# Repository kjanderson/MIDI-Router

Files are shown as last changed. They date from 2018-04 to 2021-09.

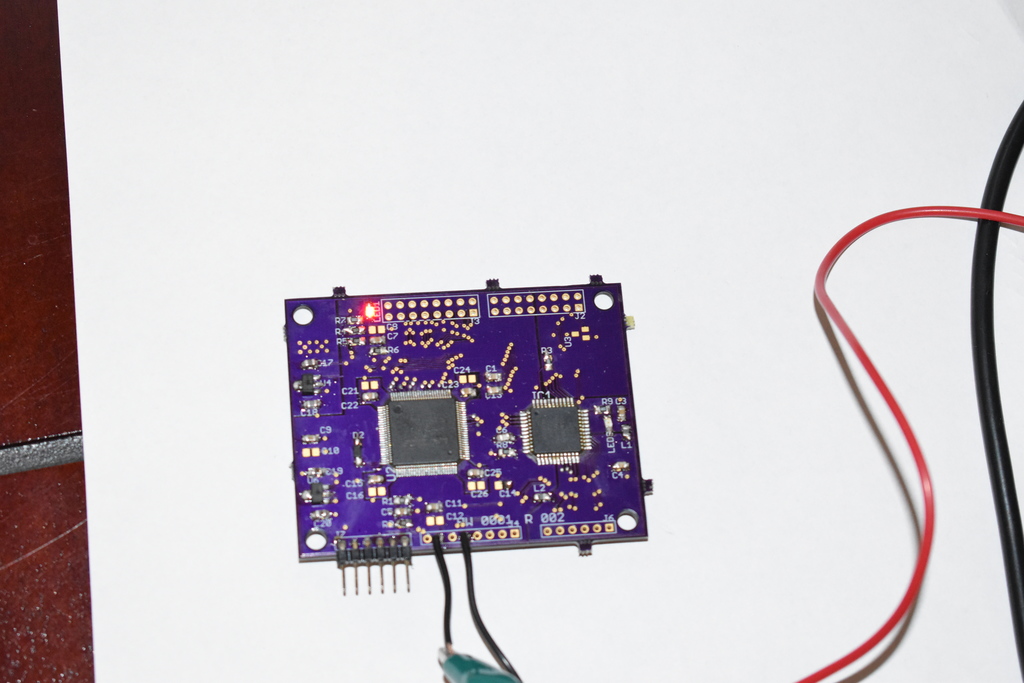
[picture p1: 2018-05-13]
05-implementation/01-pcb/MCU/eagle/mcu-pcb-bringup.jpg

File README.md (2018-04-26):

# MIDI-Router
PIC24/FPGA code to route MIDI data on prototype hardware.

The objective of this project is to build a prototype that is able to route MIDI
signals from source to destination automatically.

The hardware provides 4 MIDI inputs, 4 MIDI thru's, and 4 MIDI outputs.
This software project implements the routing of the inputs to the outputs.

Notes
 - USB is copied from the MLA USB Framework
 - USB-app is copied from the application example in the MLA
 - USB-bsp is copied from the application example in the MLA

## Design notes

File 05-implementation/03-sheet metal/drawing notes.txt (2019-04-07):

Mike@SchorrMetals.com
24 gauge steel, drawing, qty.

panel outline dimensions
    426 mm (16.772 inch) wide
    37.0 mm (1.457 inch) tall
screw hole positions
    1.109 inches vertical
    2.70, 3.2974 mm (0.106, 0.130 inch), 4.5 mm (0.177 inch) diameter
    2.70, 33.697 mm (0.106, 1.327 inch), 4.5 mm (0.177 inch) diameter
    42.00, 3.7974 mm (1.654, 0.150 inch), 4.0 mm (0.157 inch) diameter
    213.00, 3.7974 mm (8.386, 0.150 inch), 4.0 mm (0.157 inch) diameter
    384.00, 3.7974 mm (15.118, 0.150 inch), 4.0 mm (0.157 inch) diameter
    423.30, 3.2974 mm (16.665, 0.130 inch), 4.5 mm (0.177 inch) diameter
    423.30, 33.6974 mm (16.665, 1.327 inch), 4.5 mm (0.177 inch) diameter

120 outlet
holes: 3.5 mm (0.138 inch) diameter
       36 mm (1.417 inch) apart
cutout: 27.3 mm (1.075 inch) tall
        31.4 mm (1.236 inch) wide

USB connector
holes: 3.20 mm (0.126 inch) diameter
       22.0 mm (0.866 inch) apart
cutout: 13.70 mm (0.539 inch) tall
        14.70 mm (0.579 inch) wide

120 outlet
holes: 3.4 mm (0.134 inch)
       40.0 mm (1.575 inch) apart
cutout: 30.3 mm (1.193 inch) wide
        22.3 mm (0.878 inch) tall

spacing of back panel:
    1.0 mm thick bottom
    1.0 mm thick top
    0.75 mm gap between bottom
    0.75 mm gap between top
    0.25 mm gap to bottom lip
    1.5 mm bottom lip
    0.25 mm gap to top lip
    1.5 mm top lip
    3.256 mm (0.128 inch) overhang on top
    
    bottom surface at y=-0.75 mm (0.0295 inch)
    0.5" standoff
    0.062" PCB thickness
    10.0 mm (0.394 inch) DIN height
    DIN5 holes centered at y=0.927 inch
0.25" standoffs instead of 0.5" standoffs
    DIN5 holes centered at y=0.677 inch

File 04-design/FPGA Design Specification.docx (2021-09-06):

# FPGA Design Specification

Revision 0.1

Korwin Anderson

# Revision History

Date | Revision | Description
07/22/2021 | 0.1 | Initial version

# Introduction

This document provides the FPGA design specification for the MIDI Router box.

# Architecture

Figure 1 illustrates the FPGA design architecture. All modules are clocked at 250 KHz.

SPI

FIFO

MIDI TX Output

Figure 1: Architecture of MIDI Router FPGA design

# Design

## SPI Slave (Write Only)

This module implements an SPI Slave device that supports write-only operations to the FIFO.

## FIFO

This module implements a hardware FIFO using one of the block RAMs of the iCE40 HX device. This is modeled after something like the 74xx222 device, following guidance on https://www.asic-world.com/.

## MIDI TX Output

This module instantiates a standard UART transmitter, with glue logic to interface to the FIFO. The output clock is divided (internal to this module) by 8 to provide the required 31.25 KHz baud rate.

IDLE

READ FIFO

START TX

WAIT TX

Current State | FIFO empty | UART done | Next State
IDLE | Y | | IDLE
IDLE | N | | READ FIFO
READ FIFO | | | START TX
START TX | | | WAIT TX
WAIT TX | | N | WAIT TX
WAIT TX | | Y | IDLE

# Interface

## Electrical

All inputs interface to the FPGA’s 3.3V input ports.

All outputs interface to the FPGA’s 3.3V output ports.

Power up/down requirements are per the iCE40 HX datasheet. No special sequencing requirements exist for this device.

## Software

There is no software interface to the FPGA design.

## Signal List

midi_in[3:0]: vector of 4 input MIDI signals

spi_sck: programming/debug interface. Not currently used.

spi_mosi: programming/debug interface. Not currently used.

spi_miso: programming/debug interface. Not currently used.

spi_ss: programming/debug interface. Not currently used.

gpio_fbin[3:0]: debug interface. Not currently used.

gpio_bin[15:0]: debug interface. Not currently used.

midi_out[3:0]: vector of 4 output MIDI signals

# Resource Estimate

## Device Utilization

Flip Flops: 50

LUTs: 75

## Power Estimate

<1mW

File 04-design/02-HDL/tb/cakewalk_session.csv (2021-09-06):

Time [us] | MIDI IN 2-Piano | MIDI IN 3-PC
0 | 1 | 1
2297011 | 0 | 1
2297172 | 1 | 1
2297235 | 0 | 1
2297268 | 1 | 1
2297330 | 0 | 1
2297620 | 1 | 1
2297650 | 0 | 1
2297684 | 1 | 1
2297714 | 0 | 1
2297780 | 1 | 1
2297906 | 0 | 1
2297940 | 1 | 1
2297970 | 0 | 1
2297998 | 0 | 1
2298132 | 1 | 1
2298161 | 1 | 1
2298194 | 0 | 1
2298223 | 0 | 1
2298228 | 1 | 1
2298254 | 1 | 1
2298290 | 0 | 1
2298320 | 0 | 1
2298484 | 1 | 1
2298514 | 0 | 1
2298580 | 1 | 1
2298606 | 1 | 1
2298610 | 0 | 1
2298637 | 0 | 1
2298672 | 0 | 1
2298703 | 0 | 1
2298769 | 0 | 1
2298897 | 0 | 1
2298900 | 1 | 1
2298928 | 1 | 1
2298930 | 0 | 1
2298959 | 0 | 1
2299118 | 0 | 1
2299156 | 1 | 1
2299184 | 1 | 1
2299215 | 1 | 1
2299250 | 0 | 1
2299280 | 0 | 1
2299470 | 0 | 1
2299501 | 0 | 1
2299539 | 1 | 1
2299567 | 1 | 1
2299570 | 0 | 1
2299598 | 0 | 1
2299731 | 1 | 1
2299793 | 0 | 1
2299827 | 1 | 1
2299889 | 0 | 1
2299920 | 0 | 1
2299923 | 1 | 1
2300017 | 0 | 1
2300144 | 0 | 1
2300179 | 1 | 1
2300209 | 0 | 1
2300237 | 0 | 1
2300243 | 1 | 1
2300465 | 0 | 1
2300499 | 1 | 1
2300528 | 1 | 1
2300529 | 0 | 1
2300559 | 0 | 1
2300691 | 1 | 1
2300717 | 1 | 1
2300753 | 0 | 1
2300783 | 0 | 1
2300787 | 1 | 1
2300814 | 1 | 1
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

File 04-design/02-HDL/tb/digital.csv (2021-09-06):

Time [s] | MIDI IN 2-Piano | MIDI IN 3-PC | MIDI OUT 2-Synth | MIDI OUT 3-No Load | Channel 4 | Channel 5 | Channel 6 | Channel 7
-2.297011000 | 1 | 1 | 1 | 1 | 1 | 1 | 1 | 1
-0.000000000 | 0 | 1 | 1 | 1 | 1 | 1 | 1 | 1
0.000161000 | 1 | 1 | 1 | 1 | 1 | 1 | 1 | 1
0.000224000 | 0 | 1 | 1 | 1 | 1 | 1 | 1 | 1
0.000257000 | 1 | 1 | 1 | 1 | 1 | 1 | 1 | 1
0.000319000 | 0 | 1 | 1 | 1 | 1 | 1 | 1 | 1
0.000609000 | 1 | 1 | 1 | 1 | 1 | 1 | 1 | 1
0.000639000 | 0 | 1 | 1 | 1 | 1 | 1 | 1 | 1
0.000673000 | 1 | 1 | 1 | 1 | 1 | 1 | 1 | 1
0.000703000 | 0 | 1 | 1 | 1 | 1 | 1 | 1 | 1
0.000769000 | 1 | 1 | 1 | 1 | 1 | 1 | 1 | 1
0.000895000 | 0 | 1 | 1 | 1 | 1 | 1 | 1 | 1
0.000929000 | 1 | 1 | 1 | 1 | 1 | 1 | 1 | 1
0.000959000 | 0 | 1 | 1 | 1 | 1 | 1 | 1 | 1
0.000987000 | 0 | 1 | 0 | 1 | 1 | 1 | 1 | 1
0.001121000 | 1 | 1 | 0 | 1 | 1 | 1 | 1 | 1
0.001150000 | 1 | 1 | 1 | 1 | 1 | 1 | 1 | 1
0.001183000 | 0 | 1 | 1 | 1 | 1 | 1 | 1 | 1
0.001212000 | 0 | 1 | 0 | 1 | 1 | 1 | 1 | 1
0.001217000 | 1 | 1 | 0 | 1 | 1 | 1 | 1 | 1
0.001243000 | 1 | 1 | 1 | 1 | 1 | 1 | 1 | 1
0.001279000 | 0 | 1 | 1 | 1 | 1 | 1 | 1 | 1
0.001309000 | 0 | 1 | 0 | 1 | 1 | 1 | 1 | 1
0.001473000 | 1 | 1 | 0 | 1 | 1 | 1 | 1 | 1
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

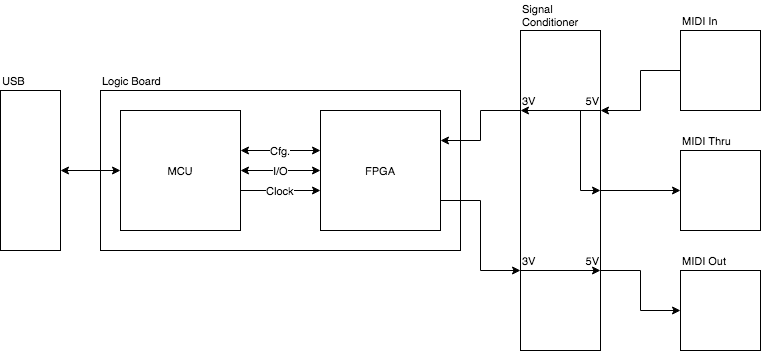
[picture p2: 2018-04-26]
01-requirements/system specification figures/system drawing.png

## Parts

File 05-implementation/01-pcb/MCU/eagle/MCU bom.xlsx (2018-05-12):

Part | Value | Device | Package | Description | RATING | SPICEPREFIX
C1 | 100n | C-EUC0805 | C0805 | CAPACITOR, European symbol |  | C
C3 | 100n | C-EUC0805 | C0805 | CAPACITOR, European symbol |  | C
C4 | 100n | C-EUC0805 | C0805 | CAPACITOR, European symbol |  | C
C5 | 100n | C-EUC0805 | C0805 | CAPACITOR, European symbol |  | C
C6 | 10u | C-EUC0805 | C0805 | CAPACITOR, European symbol | 6.3V | C
C7 | 100n | C-EUC0805 | C0805 | CAPACITOR, European symbol |  | C
C8 | 10n | C-EUC0805 | C0805 | CAPACITOR, European symbol |  | C
C9 | 100n | C-EUC0805 | C0805 | CAPACITOR, European symbol |  | C
C10 | 10n | C-EUC0805 | C0805 | CAPACITOR, European symbol |  | C
C11 | 100n | C-EUC0805 | C0805 | CAPACITOR, European symbol |  | C
C12 | 10n | C-EUC0805 | C0805 | CAPACITOR, European symbol |  | C
C13 | 100n | C-EUC0805 | C0805 | CAPACITOR, European symbol |  | C
C14 | 10n | C-EUC0805 | C0805 | CAPACITOR, European symbol |  | C
C15 | 100n | C-EUC0805 | C0805 | CAPACITOR, European symbol |  | C
C16 | 10n | C-EUC0805 | C0805 | CAPACITOR, European symbol |  | C
C17 | 1u | C-EUC0805 | C0805 | CAPACITOR, European symbol |  | C
C18 | 1u | C-EUC0805 | C0805 | CAPACITOR, European symbol |  | C
C19 | 1u | C-EUC0805 | C0805 | CAPACITOR, European symbol |  | C
C20 | 1u | C-EUC0805 | C0805 | CAPACITOR, European symbol |  | C
C21 | 100n | C-EUC0805 | C0805 | CAPACITOR, European symbol |  | C
C22 | 10n | C-EUC0805 | C0805 | CAPACITOR, European symbol |  | C
C23 | 100n | C-EUC0805 | C0805 | CAPACITOR, European symbol |  | C
C24 | 10n | C-EUC0805 | C0805 | CAPACITOR, European symbol |  | C
C25 | 100n | C-EUC0805 | C0805 | CAPACITOR, European symbol |  | C
C26 | 10n | C-EUC0805 | C0805 | CAPACITOR, European symbol |  | C
D2 | MBR0520 | MBR0520 | MBR0520-SOD-123_MINI-SMA
IC1 | PIC24FJ128GB204 | PIC24FJ128GB204 | TQFP44 | PIC24FJ64GA00416-bit microcontroller
J2 | ARDUINO-CONN-8X2 | ARDUINO-CONN-8X2 | ARDUINO-CONN-8X2
J3 | ARDUINO-CONN-8X2 | ARDUINO-CONN-8X2 | ARDUINO-CONN-8X2
J4 | ARDUINO-CONN-8 | ARDUINO-CONN-8 | ARDUINO-CONN-8
J6 | ARDUINO-CONN-6 | ARDUINO-CONN-6 | ARDUINO-CONN-6
J7 | PICKIT-ICSP | PICKIT-ICSP | PICKIT-ICSP
L1 | BEAD | BEAD | L0805
L2 | BEAD | BEAD | L0805
LED1 |  | LEDCHIP-LED0805 | CHIP-LED0805 | LED
LED3 |  | LEDCHIP-LED0805 | CHIP-LED0805 | LED
R1 | 100 | R-EU_R0805 | R0805 | RESISTOR, European symbol
R2 | 10K | R-EU_R0805 | R0805 | RESISTOR, European symbol
R3 | 100 | R-EU_R0805 | R0805 | RESISTOR, European symbol
R4 | 10K | R-EU_R0805 | R0805 | RESISTOR, European symbol
R5 | 10K | R-EU_R0805 | R0805 | RESISTOR, European symbol
R6 | 10K | R-EU_R0805 | R0805 | RESISTOR, European symbol
R7 | 680 | R-EU_R0805 | R0805 | RESISTOR, European symbol
R8 | 10 | R-EU_R0805 | R0805 | RESISTOR, European symbol
R9 | 680 | R-EU_R0805 | R0805 | RESISTOR, European symbol
U2 | ICE40-HX1K-VQFP100 | ICE40-HX1K-VQFP100 | TQFP100-14X14
U3 | SP0502BAHT-SOT23 | SP0502BAHT-SOT23 | SOT23
U4 | MCP1700-SOT89 | MCP1700-SOT89 | MCP1700-SOT89
U6 | MCP1700-SOT89 | MCP1700-SOT89 | MCP1700-SOT89

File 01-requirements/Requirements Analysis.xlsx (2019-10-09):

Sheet: System Diagram
 |  |  |  | 5V
 |  |  |  | 3.3V |  | 120 VAC
 |  |  |  | 1.2V | 5V | 5V
 |  |  |  | 5V | 5V | 5V
 |  |  | FPGA | MIDI input | MIDI Input | MIDI Input
 | MCU | Configuration |  | Ch A | Ch A | Ch A
 |  | CRESET |  | Ch B | Ch B | Ch B
 |  | CDONE |  | Ch C | Ch C | Ch C
 |  |  |  | Ch D | Ch D | Ch D
 |  | SPI
 |  | UART data |  |  | 5V | 5V
LED |  | switch matrix |  |  | MIDI Thru | MIDI Thru
 |  | mute outputs |  |  | Ch A | Ch A
USB |  |  |  |  | Ch B | Ch B
CDC class |  | Functional I/O |  |  | Ch C | Ch C
 |  | UART interrupt |  |  | Ch D | Ch D
 |  | spare
 |  | spare |  | 5V | 5V | 5V
 |  | spare |  | MIDI Output | MIDI Output | MIDI Output
 |  |  |  | Ch A | Ch A | Ch A
 |  | Clock |  | Ch B | Ch B | Ch B
 |  |  |  | Ch C | Ch C | Ch C
 |  |  |  | Ch D | Ch D | Ch D
 |  |  |  | I2C
 |  |  |  | NV memory
 |  |  |  | LED's 1-8
 |  |  |  | LED's 9-16
 |  |  |  | PB's 1-8
 |  |  |  | PB's 9-16

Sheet: Fabric Utilization
Pin Count | Function | Quantity | Cost
UART RX | 8 | 4 | 32
UART Clock prescaler | 6 | 1 | 6
UART State Machine | 2 | 4 | 8
UART SR | 8 | 4 | 32
UART RX register | 8 | 4 | 32
UART RX voting | 3 | 4 | 12
UART RX sampling | 4 | 4 | 16
SPI module misc | 1 | 1 | 1
SPI shift register | 8 | 1 | 8
SPI state machine | 27 | 1 | 27
 | 0 | 0 | 0
UART TX SR | 8 | 4 | 32
Subtotal |  |  | 206
Capacity |  |  | 1280
Utilization |  |  | 0.1609375

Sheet: FPGA Pin Use
 | iCE40 Pinout HX1K
Order | Pin Function | Pin Type | Bank | (VQ100) 100-Pin VQFP Pin Number | (CB132) 132-Ball csBGA Ball Number | (TQ144) 144-Pin TQFP Pin Number | Use
1 | IOL_1A | DPIO | 3 | 1 | B1 | 1
2 | IOL_1B | DPIO | 3 | 2 | C1 | 2
3 | IOL_2A | DPIO | 3 | 3 | C3 | 3
4 | IOL_2B | DPIO | 3 | 4 | D3 | 4
106 | GND | GND | GND | 5 | A9 | 5
130 | VCCIO_3 | VCCIO | VCCIO | 6 | E3 | 6
5 | IOL_3A | DPIO | 3 | 7 | D4 | 7
6 | IOL_3B | DPIO | 3 | 8 | E4 | 8
9 | IOL_5A | DPIO | 3 | 9 | F4 | 11
10 | IOL_5B | DPIO | 3 | 10 | F3 | 12
119 | VCC | VCC | VCC | 11 | F8 | 27
11 | IOL_6A | DPIO | 3 | 12 | H3 | 19
12 | IOL_6B_GBIN7 | GBIN | 3 | 13 | H1 | 20 | REFO
131 | VCCIO_3 | VCCIO | VCCIO | 14 | J6 | 30
13 | IOL_7A_GBIN6 | GBIN | 3 | 15 | G1 | 21 | FBIN3
14 | IOL_7B | DPIO | 3 | 16 | G3 | 22 | FBIN2
113 | GND | GND | GND | 17 | H7 | 132
15 | IOL_8A | DPIO | 3 | 18 | G4 | 23 | FBIN1
16 | IOL_8B | DPIO | 3 | 19 | H4 | 24 | FBIN0
19 | IOL_10A | DPIO | 3 | 20 | - | 28 | BIN4
20 | IOL_10B | DPIO | 3 | 21 | - | 29 | BIN5
132 | VCCIO_3 | VCCIO | VCCIO | 22 | K1 | -
114 | GND | GND | GND | 23 | H8 | 140
23 | IOL_12A | DPIO | 3 | 24 | M1 | 33 | BIN6
24 | IOL_12B | DPIO | 3 | 25 | L1 | 34 | BIN7
29 | IOB_26 | PIO | 2 | 26 | P2 | 39 | BIN8
30 | IOB_27 | PIO | 2 | 27 | P3 | 41 | BIN14
31 | IOB_28 | PIO | 2 | 28 | M4 | 42 | BIN9
32 | IOB_29 | PIO | 2 | 29 | L5 | 43 | BIN15
33 | IOB_30 | PIO | 2 | 30 | P4 | 44 | BIN10
128 | VCCIO_2 | VCCIO | VCCIO | 31 | J9 | 46
107 | GND | GND | GND | 32 | F1 | 13
37 | IOB_35_GBIN5 | GBIN | 2 | 33 | P7 | 49 | BIN16
38 | IOB_36_GBIN4 | GBIN | 2 | 34 | P8 | 50 | BIN11
120 | VCC | VCC | VCC | 35 | G6 | 51
39 | IOB_34 | PIO | 2 | 36 | M7 | 52 | BIN17
40 | IOB_37 | PIO | 2 | 37 | P9 | 56 | BIN12
129 | VCCIO_2 | VCCIO | VCCIO | 38 | M5 | 57
108 | GND | GND | GND | 39 | F7 | 14
44 | IOB_41 | PIO | 2 | 40 | M9 | 62 | BIN18
45 | IOB_42_CBSEL0 | PIO | 2 | 41 | L9 | 63 | BIN13
46 | IOB_43_CBSEL1 | PIO | 2 | 42 | P10 | 64 | BIN19
47 | CDONE | CONFIG | 2 | 43 | M10 | 65 | CDONE
48 | CRESET_B | CONFIG | 2 | 44 | L10 | 66 | CRESET
49 | IOB_44_SDO | SPI | SPI | 45 | M11 | 67 | MISO
50 | IOB_45_SDI | SPI | SPI | 46 | P11 | 68 | MOSI
109 | GND | GND | GND | 47 | G7 | 59
51 | IOB_46_SCK | SPI | SPI | 48 | P12 | 70 | SCK
52 | IOB_47_SS | SPI | SPI | 49 | P13 | 71 | SS
53 | VCC_SPI | SPI | SPI | 50 | L11 | 72
59 | IOR_52 | PIO | 1 | 51 | L14 | 78
60 | IOR_53 | PIO | 1 | 52 | K12 | 79
61 | IOR_54 | PIO | 1 | 53 | K11 | 80
62 | IOR_55 | PIO | 1 | 54 | K14 | 81
110 | GND | GND | GND | 55 | G8 | 69
63 | IOR_56 | PIO | 1 | 56 | J12 | 87
64 | IOR_57 | PIO | 1 | 57 | J11 | 88
126 | VCCIO_1 | VCCIO | VCCIO | 58 | F9 | 100
65 | IOR_58 | PIO | 1 | 59 | H12 | 90
66 | IOR_59 | PIO | 1 | 60 | H11 | 91
121 | VCC | VCC | VCC | 61 | H9 | 92
67 | IOR_60_GBIN3 | GBIN | 1 | 62 | F14 | 93
68 | IOR_61_GBIN2 | GBIN | 1 | 63 | G14 | 94
70 | IOR_63 | PIO | 1 | 64 | G11 | 96
71 | IOR_64 | PIO | 1 | 65 | F12 | 97
72 | IOR_65 | PIO | 1 | 66 | E14 | 98
127 | VCCIO_1 | VCCIO | VCCIO | 67 | H14 | 89
74 | IOR_67 | PIO | 1 | 68 | E12 | 101
75 | IOR_68 | PIO | 1 | 69 | D14 | 102
111 | GND | GND | GND | 70 | G9 | 86
76 | IOR_69 | PIO | 1 | 71 | C14 | 104
77 | IOR_70 | PIO | 1 | 72 | E11 | 105
78 | IOR_71 | PIO | 1 | 73 | B14 | 106
79 | IOR_72 | PIO | 1 | 74 | D12 | 107
80 | VPP_2V5 | VPP | VPP | 75 | A14 | 108
81 | VPP_FAST | VPP | VPP | 76 | A13 | 109
122 | VCC | VCC | VCC | 77 | J4 | 111
82 | IOT_73 | PIO | 0 | 78 | C12 | 112
83 | IOT_74 | PIO | 0 | 79 | A12 | 113
84 | IOT_75 | PIO | 0 | 80 | C11 | 114
86 | IOT_77 | PIO | 0 | 81 | D11 | 116
87 | IOT_78 | PIO | 0 | 82 | A10 | 117
88 | IOT_79 | PIO | 0 | 83 | D10 | 118
115 | GND | GND | GND | 84 | J14 | -
89 | IOT_80 | PIO | 0 | 85 | C9 | 119
90 | IOT_81 | PIO | 0 | 86 | D9 | 120
91 | IOT_82 | PIO | 0 | 87 | C8 | 121
125 | VCCIO_0 | VCCIO | VCCIO | 88 | F6 | 123
93 | IOT_84_GBIN1 | GBIN | 0 | 89 | A7 | 128
94 | IOT_85_GBIN0 | GBIN | 0 | 90 | A6 | 129
95 | IOT_86 | PIO | 0 | 91 | C7 | -
124 | VCCIO_0 | VCCIO | VCCIO | 92 | A8 | 133
96 | IOT_87 | PIO | 0 | 93 | D7 | 134
97 | IOT_88 | PIO | 0 | 94 | C6 | 135
98 | IOT_89 | PIO | 0 | 95 | A5 | 136
99 | IOT_90 | PIO | 0 | 96 | A4 | 137
100 | IOT_91 | PIO | 0 | 97 | D6 | 138
112 | GND | GND | GND | 98 | H6 | 103
102 | IOT_93 | PIO | 0 | 99 | A2 | 141
104 | IOT_95 | PIO | 0 | 100 | A1 | 143
7 | IOL_4A | DPIO | 3 | - | D1 | 9
8 | IOL_4B | DPIO | 3 | - | E1 | 10
17 | IOL_9A | DPIO | 3 | - | J1 | 25
18 | IOL_9B | DPIO | 3 | - | J3 | 26
21 | IOL_11A | DPIO | 3 | - | K4 | 31
22 | IOL_11B | DPIO | 3 | - | K3 | 32
25 | GNDPLL | GNDPLL | GNDPLL | - | P1 | 35
26 | VCCPLL | VCCPLL | VCCPLL | - | N1 | 36
27 | IOB_24 | PIO | 2 | - | M3 | 37
28 | IOB_25 | PIO | 2 | - | L4 | 38
34 | IOB_31 | PIO | 2 | - | L6 | 45
35 | IOB_32 | PIO | 2 | - | P5 | 47
36 | IOB_33 | PIO | 2 | - | M6 | 48
41 | IOB_38 | PIO | 2 | - | L7 | 58
42 | IOB_39 | PIO | 2 | - | M8 | 60
43 | IOB_40 | PIO | 2 | - | L8 | 61
54 | IOR_48 | PIO | 1 | - | M12 | 73
55 | IOR_49 | PIO | 1 | - | P14 | 74
56 | IOR_50 | PIO | 1 | - | L12 | 75
57 | IOR_51 | PIO | 1 | - | N14 | 76
58 | NC | NC | NC | - | M14 | 77
69 | IOR_62 | PIO | 1 | - | G12 | 95
73 | IOR_66 | PIO | 1 | - | F11 | 99
85 | IOT_76 | PIO | 0 | - | C10 | 115
92 | IOT_83 | PIO | 0 | - | D8 | 122
101 | IOT_92 | PIO | 0 | - | C5 | 139
103 | IOT_94 | PIO | 0 | - | D5 | 142
105 | IOT_96 | PIO | 0 | - | C4 | 144
116 | GND | GND | GND | - | J8 | -
117 | GND | GND | GND | - | L3 | -
118 | GND | GND | GND | - | P6 | -
123 | VCC | VCC | VCC | - | J7 | -
133 | NC | NC | NC | - | A3 | 15
134 | NC | NC | NC | - | A11 | 16
135 | NC | NC | NC | - | - | 17
136 | NC | NC | NC | - | - | 18
137 | NC | NC | NC | - | - | 40
138 | NC | NC | NC | - | - | 53
139 | NC | NC | NC | - | - | 54
140 | NC | NC | NC | - | - | 55
141 | NC | NC | NC | - | - | 82
142 | NC | NC | NC | - | - | 83
143 | NC | NC | NC | - | - | 84
144 | NC | NC | NC | - | - | 85
145 | NC | NC | NC | - | - | 110
146 | NC | NC | NC | - | - | 124
147 | NC | NC | NC | - | - | 125
148 | NC | NC | NC | - | - | 126
149 | NC | NC | NC | - | - | 127
150 | NC | NC | NC | - | - | 130
151 | NC | NC | NC | - | - | 131

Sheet: PIC24
Pin | Name (PIC24FJ128GB204 - 44 pin) | 5V Tolerant | Function
1 | C1INC/C2INC/C3INC/RP9/SDA1/T1CK/CTED4/PMD3/CN21/RB9 |  | FBIN0
2 | RP22/PMA1/PMALH/CN18/RC6 | X | FBIN1
3 | RP23/PMA0/PMALL/CN17/RC7 | X | FBIN2
4 | RP24/PMA5/CN20/RC8 | X | FBIN3
5 | RP25/CTED7/PMA6/CN19/RC9 | X
6 | VBAT
7 | VCAP
8 | RP10/CTED11/CN16/PGD2/D+/RB10 | X | USB-D+
9 | REFI/RP11/CTED9/CN15/PGC2/D-/RB11 | X | USB-D-
10 | VUSB3V3 |  | USB-VUSB (VDD)
11 | AN7/C1INC/REFO/RP13/CTPLS/PMRD/CN13/RB13 |  | REFO (32 MHz to FPGA)
12 | TMS/PMA2/PMALU/CN36/RA10 | X
13 | TCK/PMA7/CN33/RA7 | X
14 | CVREF/AN6/C3INB/RP14/RTCC/CTED5/CN12/RB14
15 | AN9/C3INA/RP15/T3CK/T2CK/CTED6/PMA14/CS1/CN11/PMCS/PMCS1/RB15
16 | AVSS/VSS |  | VSS
17 | AVDD |  | AVDD
18 | MCLR |  | ICSP: MCLR
19 | CVREF+/VREF+/AN0/C3INC/RP5/ASDA1(1)/CTED1/CN2/PMD7/PGD3/RA0 |  | PGD
20 | CVREF-/VREF-/AN1/C3IND/RP6/ASCL1(1)/CTED2/CN3/PGC3/RA1 |  | PGC
21 | AN2/CTCMP/C2INB/RP0/CN4/PGD1/HLVDIN/PMD0/RB0 |  | AN5
22 | AN3/C2INA/RP1/CTED12/CN5/PMD1/PGC1/RB1 |  | AN4
23 | AN4/C1INB/RP2/SDA2/T5CK/T4CK/CTED13/CN6/PMD2/RB2 |  | AN3
24 | AN5/C1INA/RP3/SCL2/CTED8/CN7/PMWR/RB3 |  | AN2
25 | AN10/RP16/PMBE1/CN8/RC0 |  | AN1
26 | AN11/RP17/CN9/RC1 |  | AN0
27 | AN12/RP18/PMACK1/CN10/RC2
28 | VDD |  | VDD
29 | VSS |  | VSS
30 | OSCI/C1IND/CLKI/PMCS1/CN30/RA2
31 | OSCO/C2IND/CLKO/CN29/RA3
32 | TDO/PMA8/CN34/RA8 | X
33 | SOSCI/CN1/RPI4/RB4 | X | MODE (LED)
34 | SOSCO/SCLKI/CN0/RA4 | X | CRESET
35 | TDI/PMA9/CN35/RA9 | X | CDONE
36 | RP19/PMBE0/CN28/RC3 | X | SPI: SS
37 | RP20/PMA4/CN25/RC4 | X | SPI: SCK
38 | RP21/PMA3/CN26/RC5 | X | SPI: MISO
39 | VSS
40 | VDD
41 | CN27/USBID/RB5 | X
42 | PMD6/CN24/VBUS/RB6 | X | USB-VBUS
43 | RP7/CTED3/INT0/CN23/PMD5/RB7 | X | SPI: MOSI
44 | RP8/SCL1/CTED10/PMD4/CN22/USBOEN/RB8 | X
 |  |  | nice to have's: 1. 2 peripherals to MCU 2. 2 GPIO status to MCU

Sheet: Requirements-QFD1
 |  | Technical criteria
Need | Importance | Logic board component provides USB function | Signal Conditioner component provides USB interface | Signal Conditioning component provides non-volatile storage | Logic board component provides input sampling | Signal Conditioner component provides input conditioning | Logic Board component provides MIDI THRU function | Signal Conditioner component provides MIDI THRU conditioning | Logic Board component provides MIDI output function | Signal Conditioner component provides MIDI output conditioning | MIDI Input component provides MIDI input connections | MIDI Output component provides MIDI THRU connections | MIDI Output component provides MIDI output connections | Wiring component provides 120 VAC connection | Wiring component provides USB connector | Wiring component provides input power switch | I/O component provides LED interface | I/O component provides PB interface | Logic Board Software component provides terminal interface | Logic Board Firmware component provides low-latency MIDI switching | Logic Board Firmware provides highly available MIDI switching function | Logic Board Firmware component provides highly available USB function | Logic Board Firmware component provides ability to update application code | Logic Board Firmware component supports non-volatile storage
I need 4 inputs, 4 thru's, and 4 outputs | 8 |  |  |  | 8 | 8 | 8 | 8 | 8 | 8 | 8 | 8 | 8
I need USB so I can configure the MIDI router | 5 | 8 | 8
I need 120 VAC outlet so I can use a standard interface | 2 |  |  |  |  |  |  |  |  |  |  |  |  | 8 | 8
I need a power switch on the front panel | 2 |  |  |  |  |  |  |  |  |  |  |  |  |  |  | 8
I need 4 push buttons so I can change which inputs are active. | 5 |  |  |  |  |  |  |  |  |  |  |  |  |  |  |  |  | 8
I need 4 push buttons so I can individually mute outputs | 3 |  |  |  |  |  |  |  |  |  |  |  |  |  |  |  |  | 8
Terminal emulator provides non-volatile storage of settings. | 2 |  | 8 | 8 |  |  |  |  |  |  |  |  |  |  |  |  |  | 8 |  |  |  |  |  | 8
There is an LED indication that settings were saved to persistent memory. | 2 |  | 8 | 8 |  |  |  |  |  |  |  |  |  |  |  |  |  | 8 | 8 | 8 | 8 | 8 | 8 | 8
I need a green LED for each input (4) so I know if an input is active | 5 |  |  |  |  |  |  |  |  |  |  |  |  |  |  |  | 8
I need an orange LED for each output (4) so I know I an output is active | 5 |  |  |  |  |  |  |  |  |  |  |  |  |  |  |  | 8
I need a red LED for the configuration storage function so I know my output PB configuration has been saved. | 2 |  | 8 | 8 |  |  |  |  |  |  |  |  |  |  |  |  | 8
Product fits in 19" rack mount enclosure | 2
Product is reliable | 2 |  |  |  |  |  |  |  |  |  |  |  |  |  |  |  |  |  |  | 5 | 8 | 8
Product is updateable over USB connector | 2 |  |  |  |  |  |  |  |  |  |  |  |  |  |  |  |  |  | 8 |  |  |  | 8 | 8
 |  | 40 | 88 | 48 | 64 | 64 | 64 | 64 | 64 | 64 | 64 | 64 | 64 | 16 | 16 | 16 | 96 | 96 | 32 | 26 | 32 | 32 | 32 | 48

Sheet: Requirements-QFD2
Need | Need | Importance | Logic Board EDA provides USB on signal connector | Logic Board MCU provides USB MAC and PHY | Signal Conditioner EDA provides USB on signal connector | Signal Conditioner EDA provides non-volatile storage | Logic Board EDA provides scaled MIDI input | Signal Conditioner EDA provides conditioned MIDI inputs | Logic Board EDA provides scaled MIDI THRU | Signal Conditioner EDA provides conditioned MIDI THRU | Logic Board EDA provides MIDI OUT | Signal Conditioner EDA provides conditioned MIDI OUT | MIDI Input EDA provides MIDI IN | MIDI Output EDA provides MIDI THRU | MIDI Output EDA provides MIDI THRU | Wiring craftsmanship provides 120 VAC connector | Wiring craftsmanship provides USB connector | Wiring craftsmanship provides 120 VAC power switch | Wiring craftsmanship provides mute pushbuttons | Wiring craftsmanship provides activity LEDs on front panel | Logic Board Software design provides terminal interface | Logic Board Firmware design provides low-latency MIDI switching | Logic Board Firmware design provides highly available MIDI switching function | Logic Board Firmware design provides highly available USB function | Logic Board Firmware design provides ability to update application code | Logic Board Firmware design supports non-volatile storage
Logic Board | Logic board component provides USB function | 4 |  | 8
Signal Conditioner | Signal Conditioner component provides USB interface | 8 |  |  | 8
Signal Conditioner | Signal Conditioning component provides non-volatile storage | 5 |  |  |  | 8
Logic Board | Logic board component provides input sampling | 6 | 8 |  |  |  | 8 | 5
Signal Conditioner | Signal Conditioner component provides input conditioning | 6 | 8 |  |  |  | 5 | 8
Logic Board | Logic Board component provides MIDI THRU function | 6 | 8 |  |  |  |  |  | 8 | 5
Signal Conditioner | Signal Conditioner component provides MIDI THRU conditioning | 6 |  |  | 8 |  |  |  | 5 | 8
Logic Board | Logic Board component provides MIDI output function | 6 |  |  |  |  |  |  |  |  | 8 | 5
Signal Conditioner | Signal Conditioner component provides MIDI output conditioning | 6 |  |  |  |  |  |  |  |  | 5 | 8
MIDI Input | MIDI Input component provides MIDI input connections | 6 |  |  |  |  |  |  |  |  |  |  | 8
MIDI Output | MIDI Output component provides MIDI THRU connections | 6 |  |  |  |  |  |  |  |  |  |  |  | 8 | 5
MIDI Output | MIDI Output component provides MIDI output connections | 6 |  |  |  |  |  |  |  |  |  |  |  | 5 | 8
Wiring | Wiring component provides 120 VAC connection | 2 |  |  |  |  |  |  |  |  |  |  |  |  |  | 8
Wiring | Wiring component provides USB connector | 2 |  |  |  |  |  |  |  |  |  |  |  |  |  |  | 8
Wiring | Wiring component provides input power switch | 2 |  |  |  |  |  |  |  |  |  |  |  |  |  |  |  | 8
I/O | I/O component provides LED interface | 9 |  |  |  |  |  |  |  |  |  |  |  |  |  |  |  |  |  | 8
I/O | I/O component provides PB interface | 9 |  |  |  |  |  |  |  |  |  |  |  |  |  |  |  |  | 8
Logic Board Firmware | Logic Board Software component provides terminal interface | 9 |  |  |  |  |  |  |  |  |  |  |  |  |  |  |  |  |  |  | 8
Logic Board Firmware | Logic Board Firmware component provides low-latency MIDI switching | 7 |  |  |  |  |  |  |  |  |  |  |  |  |  |  |  |  |  |  |  | 8
Logic Board Firmware | Logic Board Firmware provides highly available MIDI switching function | 9 |  |  |  |  |  |  |  |  |  |  |  |  |  |  |  |  |  |  |  |  | 8
Logic Board Firmware | Logic Board Firmware component provides highly available USB function | 9 |  |  |  |  |  |  |  |  |  |  |  |  |  |  |  |  |  |  |  |  |  | 8
Logic Board Firmware | Logic Board Firmware component provides ability to update application code | 9 |  |  |  |  |  |  |  |  |  |  |  |  |  |  |  |  |  |  |  |  |  |  | 8
 | Logic Board Firmware component supports non-volatile storage | 5 |  |  |  |  |  |  |  |  |  |  |  |  |  |  |  |  |  |  |  |  |  |  |  | 8
Technical Rank |  |  | 144 | 32 | 112 | 40 | 78 | 78 | 78 | 78 | 78 | 78 | 48 | 78 | 78 | 16 | 16 | 16 | 72 | 72 | 72 | 56 | 72 | 72 | 72 | 40
Normalized Technical Rank |  |  | 9 | 2 | 7 | 3 | 5 | 5 | 5 | 5 | 5 | 5 | 3 | 5 | 5 | 1 | 1 | 1 | 5 | 5 | 5 | 4 | 5 | 5 | 5 | 3

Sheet: FPGA Requirements-QFD2
Requirement
FPGA provides input gating
FPGA provides THRU gating
FPGA provides output assertion
Power component provides 120 VAC connection
Power component provides input power switch
LED/PB component provides LED interface
LED-PB component provides PB interface

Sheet: MCU Requirements-QFD2
Requirement
MCU provides USB
MCU provides non-volatile storage

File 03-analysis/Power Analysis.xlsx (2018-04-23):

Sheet: Power
Module | Supply | Current | Power | Notes
Logic | 5 |  | 0.0306
 | 3.3 | 0.015 | 0.0537
 | 1.2 | 0.002 | 0.0024
MIDI Input | 3.3 | 0.001 | 0.0033
MIDI Thru | 3.3 | 0.001 | 0.0033
MIDI Output | 3.3 | 0.001 | 0.0033
UI Interface | 5 | 0.010098 | 0.05049 | Power dissipated by the LDO: (5-3.3)*Io
 | 3.3 | 0.009 | 0.0297 | 1mA controller 2mA for each LED
UI Interface | 5 | 0.010098 | 0.05049 | Power dissipated by the LDO: (5-3.3)*Io
 | 3.3 | 0.009 | 0.0297 | 1mA controller 2mA for each LED
UI Interface | 5 | 0.010098 | 0.05049 | Power dissipated by the LDO: (5-3.3)*Io
 | 3.3 | 0.009 | 0.0297 | 1mA controller 2mA for each LED
Total Power |  |  | 0.18207
LED Power |  |  | 0.15147

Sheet: Net Loading
Assembly | Net-Source | Net-Sink | Load Model | voltage | load current [mA] | Rth [kΩ] | capacitance [pF] | frequency [MHz] | Power | Current | Notes
Signal Conditioning Board | MIDI IN1 | MIDI IN1-3V | resistive | 1.7 | 0.255 | 6.666666667 |  |  |  |  | No significant effect
Signal Conditioning Board | MIDI IN2 | MIDI IN2-3V | resistive | 1.7 | 0.255 | 6.666666667 |  |  |  |  | No significant effect
Signal Conditioning Board | MIDI IN3 | MIDI IN3-3V | resistive | 1.7 | 0.255 | 6.666666667 |  |  |  |  | No significant effect
Signal Conditioning Board | MIDI IN4 | MIDI IN4-3V | resistive | 1.7 | 0.255 | 6.666666667 |  |  |  |  | No significant effect
Logic Board | MIDI IN1-3V | FPGA IN1 | capacitive | 3.3 |  |  | 50 | 0.03125 | 8.5078125e-18 | 2.578125e-18 | No significant effect
Logic Board | MIDI IN2-3V | FPGA IN2 | capacitive | 3.3 |  |  | 50 | 0.03125 | 8.5078125e-18 | 2.578125e-18 | No significant effect
Logic Board | MIDI IN3-3V | FPGA IN3 | capacitive | 3.3 |  |  | 50 | 0.03125 | 8.5078125e-18 | 2.578125e-18 | No significant effect
Logic Board | MIDI IN4-3V | FPGA IN4 | capacitive | 3.3 |  |  | 50 | 0.03125 | 8.5078125e-18 | 2.578125e-18 | No significant effect
Logic Board | FPGA OUT1 | MIDI OUT1-3V | capacitive | 3.3 |  |  | 50 | 0.03125 | 8.5078125e-18 | 2.578125e-18 | No significant effect
Logic Board | FPGA OUT2 | MIDI OUT2-3V | capacitive | 3.3 |  |  | 50 | 0.03125 | 8.5078125e-18 | 2.578125e-18 | No significant effect
Logic Board | FPGA OUT3 | MIDI OUT3-3V | capacitive | 3.3 |  |  | 50 | 0.03125 | 8.5078125e-18 | 2.578125e-18 | No significant effect
Logic Board | FPGA OUT4 | MIDI OUT4-3V | capacitive | 3.3 |  |  | 50 | 0.03125 | 8.5078125e-18 | 2.578125e-18 | No significant effect
Signal Conditioning Board | MIDI OUT1-3V | MIDI OUT1 | capacitive | 5 |  |  | 50 | 0.03125 | 1.953125e-17 | 3.90625e-18 | No significant effect
Signal Conditioning Board | MIDI OUT2-3V | MIDI OUT2 | capacitive | 5 |  |  | 50 | 0.03125 | 1.953125e-17 | 3.90625e-18 | No significant effect
Signal Conditioning Board | MIDI OUT3-3V | MIDI OUT3 | capacitive | 5 |  |  | 50 | 0.03125 | 1.953125e-17 | 3.90625e-18 | No significant effect
Signal Conditioning Board | MIDI OUT4-3V | MIDI OUT4 | capacitive | 5 |  |  | 50 | 0.03125 | 1.953125e-17 | 3.90625e-18 | No significant effect
Logic Board | REFO clock | REFO clk in | resistive | 3.3 | 2.64e-15 |  |  |  |  |  | Time constant of RC circuit less than 1% of CPU clock. No significant effect
Logic Board | REFO clk out | FPGA clk | capacitive | 3.3 |  |  | 50 | 32 | 8.712e-15 | 2.64e-15 | No significant effect
Logic Board | SPI SCK | FPGA SCK | capacitive | 3.3 |  |  |  | 16 | 0 | 0 | No significant effect
Logic Board | SPI SS | FPGA SS | capacitive | 3.3 |  |  |  | 2 | 0 | 0 | No significant effect
Logic Board | SPI MOSI | FPGA SDI | capacitive | 3.3 |  |  |  | 16 | 0 | 0 | No significant effect
Logic Board | SPI MISO | FPGO SDO | capacitive | 3.3 |  |  |  | 16 | 0 | 0 | No significant effect
Logic Board | I2C SCL | I2C bus SCL | capacitive | 3.3 |  |  |  | 0.1 | 0 | 0 | No significant effect
Logic Board | I2C SDA | I2C bus SDA | capacitive | 3.3 |  |  |  | 0.1 | 0 | 0 | No significant effect
Logic Board | MODE LED | MODE LED out | resistive | 3.3 | 2 | 1.65 |  | 1e-06 |  |  | No significant effect

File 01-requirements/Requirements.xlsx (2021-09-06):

ID | Level | Text | Rationale | Verification Method | Test
R001 | L5 | FPGA design shall provide 4 MIDI inputs |  | Inspection
R002 | L5 | FPGA design shall provide 4 MIDI outputs |  | Inspection
R003 | L5 | FPGA design shall merge MIDI inputs to the MIDI outputs |  | Test
R004 | L5 | FPGA design shall adequately buffer the inputs for normal use and low bandwidth realtime events |  | Test
R005 | L6 | FPGA design shall support a 250 KHz input clock. |  | Demonstration
R006 | L6 | FPGA design shall support a 31.25 KHz UART baud rate |  | Demonstration
R007 | L7 | MIDI RX module shall buffer its response on the data bus until all data are available. |  | Simulation
R008 | L7 | MIDI RX module shall support 3-byte messages |  | Simulation
R009 | L7 | MIDI RX module shall support 2-byte messages |  | Simulation
R010 | L7 | MIDI RX module shall support the wishbone bus interface |  | Simulation
R011 | L7 | MIDI RX module shall respond to status messages, regardless of proper framing and sequence |  | Simulation
R012 | L7 | MIDI RX module shall provide realtime message data on wishbone bus |  | Simulation
R013 | L7 | MIDI RX module shall provide MIDI message data on wishbone bus |  | Simulation
R014 | L7 | MIDI RX module shall provide status on wishbone bus |  | Simulation

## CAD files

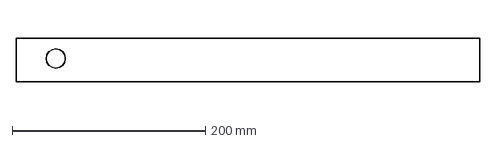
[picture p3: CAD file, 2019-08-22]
05-implementation/03-sheet metal/front panel.dxf
480.0 x 45.0 mm

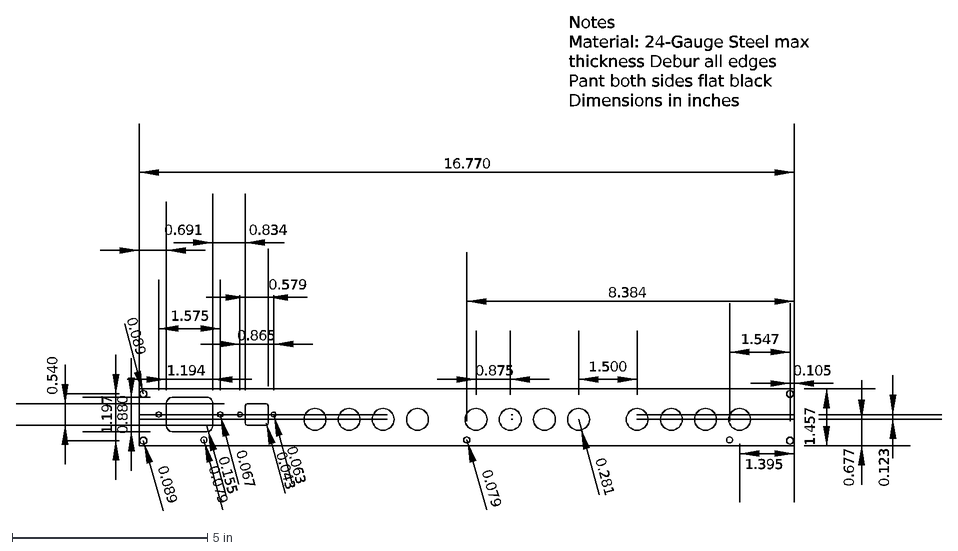
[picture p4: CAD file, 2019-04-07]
05-implementation/03-sheet metal/back panel.dxf
1.500
0.540
1.194
0.865
1.575
0.579
0.691
0.834
0.875
1.547
8.384
0.089
0.067
0.063
0.079
0.281
1.395
0.677
0.123
1.457
0.105
16.770
0.880
1.197
0.155
0.043
Notes Material: 24-Gauge Steel max thickness Debur all edges Pant both sides flat black Dimensions in inches

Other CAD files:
05-implementation/03-sheet metal/#37-1U.dwg
05-implementation/03-sheet metal/37-1U.dwg

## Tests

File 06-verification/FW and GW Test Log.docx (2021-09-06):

Firmware and Gateware Test Log

HW part number: HW002

HW revision: R001

Firmware version: 2021-04-24

Software version: 2021-04-24

Test case: test SPI interface

Test date: 2021-04-24

Test SPI interface Download firmware Power cycle the enclosure Enter debug session Step through SPI write/read cycle Verify that the MCU FW receives the byte previously written | Pass

Summary

SPI operating in mode 3 works. This provides a simple gateware interface, as there is a well define transition for each event.

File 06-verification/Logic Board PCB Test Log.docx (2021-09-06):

Test Log

HW part number: HW001

HW revision: R002

Firmware version: initial, unreleased test firmware

Software version: N/A

Test case: board bringup

Test date: 2018-05-11

Test power supplies Apply +5V to 5V power rail. Verify 1.2V appears at 1.2V power rail. Verify 3.3V appears at 3.3V power rail. | Pass Pass
Verify ICSP communications Apply +5V to 5V power rail. Verify 1.2V appears at 1.2V power rail. Verify 3.3V appears at 3.3V power rail. Verify ICSP connection succeeds. | Pass Pass Pass
Verify FPGA configuration Apply +5V to 5V power rail. Verify 1.2V appears at 1.2V power rail. Verify 3.3V appears at 3.3V power rail. Initiate debug session. Verify ICSP connection succeeds. Verify state of uFpgaResult is in main scope has a value of 1 after FPGA configuration. | Pass Pass Pass Pass
Test power LED Apply +5V to 5V power rail. Verify 1.2V appears at 1.2V power rail. Verify 3.3V appears at 3.3V power rail. Verify power LED illuminates. | Pass Pass Pass
Test mode LED Apply +5V to 5V power rail. Verify 1.2V appears at 1.2V power rail. Verify 3.3V appears at 3.3V power rail. Initiate debug session Verify ICSP connection succeeds Verify TRIS direction register sets RB4 (mode LED, pin33) to output Verify LATB register sets RB4 output (mode LED, pin33) to low level (0.0 - 0.7 V) | Pass Pass Pass Fail Fail
Investigative notes (mode LED still not working) Attempt to re-write HAL GPIO subsystem to use LATXbits.LATX format. - Observe variable view in MPLAB-X Attempt to re-write HAL GPIO subsystem to use TRISXbits.TRISX format. - Observe variable view in MPLAB-X Attempt to bypass FPGA configuration and corresponding PPS configuration. Attempt to apply 0V to LED cathode (modify fw to set pin to hi-Z). Attempt to measure resistance between µC pin 33 and LED cathode. Measure voltage applied by µC to turn LED on (shoud be approximately 0) Investigation of the part (PIC24FJ128GB204) showed pin 33 is in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 | No effect LATB4 0 No effect TRISB4 0 No effect No effect 680 Ω 2.2V Design

Summary

Design flaw in MODE connection shows that the port used for the LED cannot assert an output.

The CRESET connection also is input only. It is suspected that the FPGA configure test passed because the FPGA waits for configuration.

Proposed prototype fix: bridge pins 32 and 33 for MODE LED.

CRESET design defect cannot be easily resolved, so a new PCB will be needed.

HW part number: HW002

HW revision: R002

Firmware version: initial, unreleased test firmware

Software version: N/A

Test case: board bringup

Test date: 2018-05-13

Test mode LED Apply +5V to 5V power rail. Verify 1.2V appears at 1.2V power rail. Verify 3.3V appears at 3.3V power rail. Initiate debug session Verify ICSP connection succeeds Verify TRIS direction register sets RB4 (mode LED, pin33) to output Verify LATB register sets RB4 output (mode LED, pin33) to low level (0.0 - 0.7 V) Verify Mode LED illuminates | Pass Pass Pass Pass Pass Pass

Summary

RB4 (MODE, pin 33) and RA4 (CRESET, pin 34) are listed as input only in the device datasheet.

Bridging pins 32 and 33, and changing MODE logic (software) from RB4 (pin 33) to RA8 (pin 32) corrects the problem.

The FPGA reports as being configured correctly. Since the device presumably cannot assert CRESET, I assume this is because the FPGA simply waits for its configuration image until the MCU provides it.

HW part number: HW002

HW revision: R002

Firmware version: initial, unreleased test firmware

Software version: N/A

Test case: IP Validation: UART RX

Test date: 2021-08-21

Validate IP: UART RX Apply power to PCB Connect digital piano to MIDI input 4 (of 4) Connect logic analyzer input 1 (of 8) to MIDI input 4 (output of optocoupler) Connect logic analyzer input 2 (of 8) to FPGA output MIDI OUT 3 (0 to 3) Verify all data sent by the digital piano (MIDI input 4) is received on output 0 Verify all data sent by the digital piano (MIDI input 4) is received on output 3 | Fail Pass

Summary

FPGA output on pin 26 (MIDI output 0) appears to be non functional now. I ran a test where this was used as an output at the same time the microcontroller was using it as an output, and it looks like the microcontroller burned out the FPGA’s driver.

FPGA output on pin 29 (MIDI output 3) appears to be functioning.

I’m not sure this makes complete sense, since I thought the driver conflict was on the FBIN traces, but at least I was able to observe correct IP behavior on one of the output pins (pin 29).

I’ll have to watch this for other anomalous behavior in the future.

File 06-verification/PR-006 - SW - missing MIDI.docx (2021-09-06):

Problem Report PR-005

HW part: HW0001

HW rev: R002

Description: SW output is not recognized by synthesizers.

Steps to reproduce the problem

1. Connect piano input to MIDI IN 2
2. Connect PC output to MIDI IN 3
3. Connect PC input to MIDI THRU 2
4. Connect synth input to MIDI OUT 2
5. Turn on piano

Expected results:

1. None
2. None
3. None
4. None
5. Synthesizer should change program to Piano 1, but no effect was observed.

Investigation notes

2021-03-27 I discovered the interrupt was being received, but it was being sent to the wrong output. After correcting the output channel, I discovered that the Roland Integra-7 synthesizer received MIDI data, but doesn’t respond.

2021-03-28 After connecting an oscilloscope to the output of the opto-coupler and to the amplifier output, I observed the MIDI status message (0.25 sec period) from the piano on the input, but nothing on the output. I need to investigate the code driving the output UART further.

2021-03-29 I identified code defects in the functions MergeOutput_SendByte() and MergeOutput_TxIsr() that prevented data from being output. After testing with the Saleae logic analyzer, I identified code defects in the function _Hal_InitUart() that prevented the UART from sampling the correct data value. After correcting these code defects, the UUT works as expected with the digital piano and the Roland Integra-7 synthesizer.

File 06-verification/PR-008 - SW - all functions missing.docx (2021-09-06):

Problem Report PR-008

HW part: HW0001

HW rev: R002

SW rev: 2021-04-09

Description: All product functions missing.

Steps to reproduce the problem

1. unknown

Investigation notes

2021-05-01: While using the studio setup on 2021-05-01, MIDI data went missing. After power cycling the piano, the MIDI messages did not return. After power cycling the MIDI router, MIDI messages returned. It looks like the software became unresponsive or crashed.

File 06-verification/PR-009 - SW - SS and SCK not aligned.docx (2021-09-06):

Problem Report PR-009

HW part: HW0001

HW rev: R002

SW rev: 2021-05-15

Test log: 2021-05-15-SPI ss and sck.sal

Description: SPI SS and SCK not aligned

Steps to reproduce the problem

1. Probe SS and SCK on the PCB
2. Power on the unit

Investigation notes

2021-05-15: After configuration, SPI SS asserts (active low) 45 us before the first falling edge of SCK (OK), but only 2us after the last rising edge of SCK (fail).

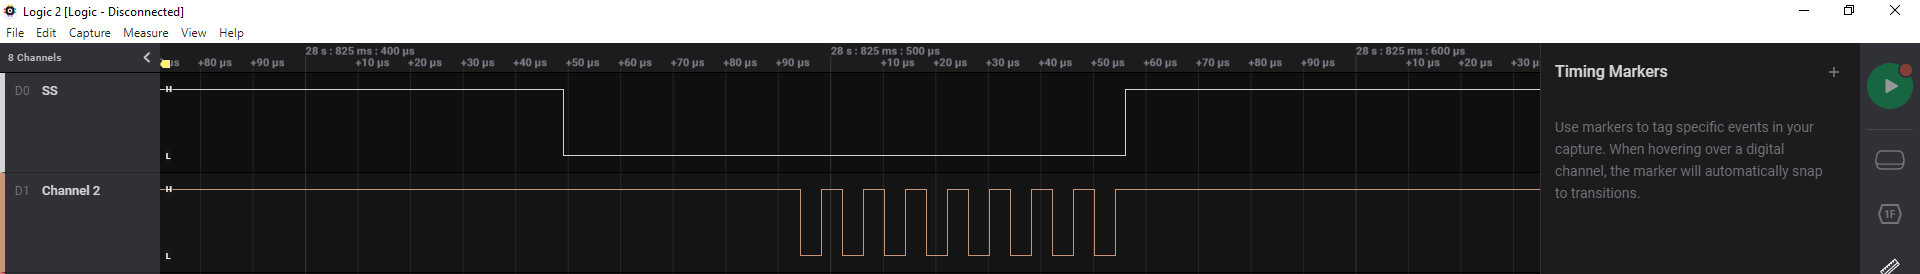
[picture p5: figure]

Screenshot of 2021-05-15-SPI ss and sck.sal

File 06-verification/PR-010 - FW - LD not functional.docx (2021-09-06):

Problem Report PR-010

HW part: HW0001

HW rev: R002

SW rev: 2021-05-15

Test log: 20210602-FPGA RAM readout over SPI.xlsx, 20210604-FPGA RAM readout over SPI.xlsx

Description: LD not functional

Steps to reproduce the problem

1. Start test software
2. Observe the response in the SPI buffer. Reads should produce data that is different from the shift register.

Investigation notes

2021-06-02: The logic for the LD signal was incorrect. I corrected this to use the async reset input to the flip flops in spislave.v, and verified that it works.

2021-06-04: Repeated the test, without the FPGA reset pin. While it is best to drive the state machine into a known state, it should not be necessary, since the startup state of all flip flops is known at power up.

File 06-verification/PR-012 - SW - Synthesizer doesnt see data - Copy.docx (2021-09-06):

Problem Report PR-012

HW part: HW0001

HW rev: R002

SW rev: 2021-07-29

Test log: 20210729-Piano session

Description: The data looks OK on the logic analyzer, but the synthesizer doesn’t see the data.

Steps to reproduce the problem

1. Start test software
2. Play piano
3. Observe no activity on the synthesizer
4. Turn piano off
5. Observe active sense warning message

Investigation notes

2021-07-29: After observing that the desired design wouldn’t fit in the device, I decided to implement the FPGA as a SPI to UART bridge, with no buffering. With no synchronization, I needed to add some delay in the microcontroller code so it didn’t miss data (on the logic analyzer). However, I noticed when I connected this to the synthesizer, it did not read any of the data. I’ll probably need to include buffering between the SPI output and the UART input in the FPGA.

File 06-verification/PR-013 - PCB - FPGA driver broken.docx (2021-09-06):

HW part number: HW002

HW revision: R002

Firmware version: initial, unreleased test firmware

Software version: N/A

Test case: IP Validation: UART RX

Test date: 2021-08-21

Steps to reproduce the problem

1. Apply power to MIDI box
2. Connect digital piano to MIDI Input 4 (of 4)
3. Apply power to digital piano
4. Connect logic analyzer input 1 (of 8) to MIDI input 4 (output of optocoupler)
5. Connect logic analyzer input 2 (of 8) to FPGA output MIDI OUT 3 (0 to 3)
6. Verify all data sent by the digital piano (MIDI input 4) is received on output 0
7. Verify all data sent by the digital piano (MIDI input 4) is received on output 3

Investigation notes

2021-08-21: FPGA output on pin 26 (MIDI output 0) appears to be non functional now. I ran a test where this was used as an output at the same time the microcontroller was using it as an output, and it looks like the microcontroller burned out the FPGA’s driver.

FPGA output on pin 29 (MIDI output 3) appears to be functioning.

I’m not sure this makes complete sense, since I thought the driver conflict was on the FBIN traces, but at least I was able to observe correct IP behavior on one of the output pins (pin 29).

I’ll have to watch this for other anomalous behavior in the future.

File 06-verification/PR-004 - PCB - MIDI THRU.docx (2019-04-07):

Problem Report PR-004

HW part: HW0002

HW rev: R002

Description: PCB hardware is not able to independently control MIDI THRU.

Analysis to demonstrate the problem:

1. MIDI THRU output signals are connected directly to MIDI IN connector

Resolution: Redesign MCU Interface PCB to allow FPGA to drive the MIDI THRU signals.

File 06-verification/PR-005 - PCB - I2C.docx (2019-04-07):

Problem Report PR-005

HW part: HW0001

HW rev: R002

Description: PCB hardware is not able to drive I2C signals.

Analysis to demonstrate the problem:

1. I2C2 signals SDA (MCU Pin 23) and SCL (MCU Pin 24) are not connected to connector J2.

Resolution: Jumper AN3 to SDA at J2-13 and AN2 to SCL at J2-11 so that the MCU Interface PCB can use them in this application. Add SDA to J2-13 and SCL to J2-11 on the MCU Interface PCB.

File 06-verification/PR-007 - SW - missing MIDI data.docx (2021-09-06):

Problem Report PR-005

HW part: HW0001

HW rev: R002

SW rev: 2021-04-09

Test record: 20210409-Cakewalk session.sal

Test record: 20210410-Piano and Cakewalk Session.sal

Description: Some MIDI data is not recognized by synthesizers.

Steps to reproduce the problem

1. Connect piano input to MIDI IN 2
2. Connect PC output to MIDI IN 3
3. Connect PC input to MIDI THRU 2
4. Connect synth input to MIDI OUT 2
5. Turn on piano
6. Record data on channel 1 (Cakewalk)
7. Record data on channel 2 (Cakewalk)
8. Playback data (Cakewalk)

Expected results:

1. None
2. None
3. None
4. None
5. Synthesizer should change program to Piano 1, but no effect was observed.
6. None
7. None
8. Synthesizer should playback sound, but note commands are consistently missed.

Investigation notes

2021-04-09: testing with the Saleae logic analyzer shows that in a SysEx sequence (0xE0 from Cakewalk), the 0x00 bytes (and only the 0x00 bytes) do not transfer to the output. Since these sequences register correctly in the previous software version, it’s not the Rx interrupt. Need to look into the algorithm for 0x00 bytes.

2021-04-10: I attempted to update the software to include a state machine that should address the issue. I still get the same type of behavior. See 20210410-Piano and Cakewalk Session.sal. In studying this measurement, it looks like the input is incorrectly sent to the output. It’s possible this is a hardware issue or a measurement issue.

2021-04-11: I realized that by loading the output with the synthesizer, it is not a valid measurement to look at the output of the amplifier. I re-ran the last test with the logic analyzer looking at the loaded and un-loaded outputs. Sure enough, the unloaded output matches much more of the inputs. I still don’t understand why the algorithm is dropping data with 0x00 in it. I’ll have to study this closer.

2021-04-17: I tracked the issue down to software defects in the state machine. Now the state machine is working, and the MIDI router is able to successfully route messages from all inputs to all outputs. With the caveat, of course, that the fourth channel is disabled to allow messages to be channeled through the MCU.

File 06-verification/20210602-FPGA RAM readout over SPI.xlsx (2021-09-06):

CMD | RSP
80 | 00
01 | 80
00 | 01
00 | 01
81 | 00
01 | 81
01 | 02
00 | 02
82 | 00
01 | 82
02 | 03
00 | 03
83 | 00
01 | 83
03 | 04
00 | 04

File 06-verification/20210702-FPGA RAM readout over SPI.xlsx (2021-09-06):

CMD | RSP | Notes
80 | 00 | Expected result
01 | 80 | Expected result
00 | 01 | Expected result
00 | 01 | Expected result
81 | 00 | Expected result
02 | 81 | Expected result
01 | 02 | Expected result
00 | 02 | Expected result
82 | 00 | Expected result
03 | 82 | Expected result
02 | 03 | Expected result
00 | 03 | Expected result
83 | 00 | Expected result
04 | 83 | Expected result
03 | 84 | Expected 0x04, not 0x84; but this value isn't critical.
00 | 04 | Expected result

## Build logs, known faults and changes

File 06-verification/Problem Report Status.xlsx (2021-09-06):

Date Reported | Date Resolved | Date Fixed | Problem Report | Status | Problem Type | Title | Summary
2018-05-11 | 2018-05-13 |  | PR-001 | Open | PCB | PCB - MODE LED | MCU hardware pin is not able to drive the MODE LED
2018-05-11 | 2018-05-13 |  | PR-002 | Open | PCB | PCB - CRESET | MCU hardware pin is not able to drive the CRESET pin
2018-08-31 | 2019-04-03 |  | PR-003 | Open | Software-app | SW - USB CDC Lockup | Software defect results in MCU firmware lockup
2019-04-03 |  |  | PR-004 | Open | PCB | FW - MIDI THRU | FPGA is not able to drive MIDI THRU signals
2019-04-03 |  |  | PR-005 | Open | PCB | PCB - I2C | MCU is not able to drive SCL/SDA signals. See PR-004
2021-03-27 | 2021-04-02 | 2021-04-02 | PR-006 | Closed | Software-app | Missing MIDI | No MIDI output observed in behavior of synthesizer.
2021-04-09 | 2021-04-17 | 2021-04-17 | PR-007 | Closed | Software-app | Missing MIDI Data | Missing MIDI note data at the synthesizer.
2021-05-01 |  |  | PR-008 | Open | Software-app | All functions missing | Systems appears to have crashed. Recovered after a power cycle.
2021-05-15 | 2021-06-02 | 2021-06-02 | PR-009 | Closed | Software-app | SS not aligned to SCK | SS provides plenty of time ahead of SCK, but it doesn't deassert when SCK does.
2021-06-01 | 2021-06-02 | 2021-06-02 | PR-010 | Closed | FPGA app | LD not functioning | LD doesn't function, which prevents reads from occurring.
2021-07-02 |  |  | PR-011 | Open | FPGA app | Error in fourth data exchange | Incorrect value exchanged on SPI bus on fourth transaction
2021-07-29 |  |  | PR-012 | Open | Software-app | Synthesizer doesn't see data | Data looks OK on the logic analyzer, but the synthesizer doesn't see the data.
2021-08-21 |  |  | PR-013 | Open | PCB | FPGA doesn't drive MIDI out 0 | FPGA is able to drive output on pin 29, but not on pin 26

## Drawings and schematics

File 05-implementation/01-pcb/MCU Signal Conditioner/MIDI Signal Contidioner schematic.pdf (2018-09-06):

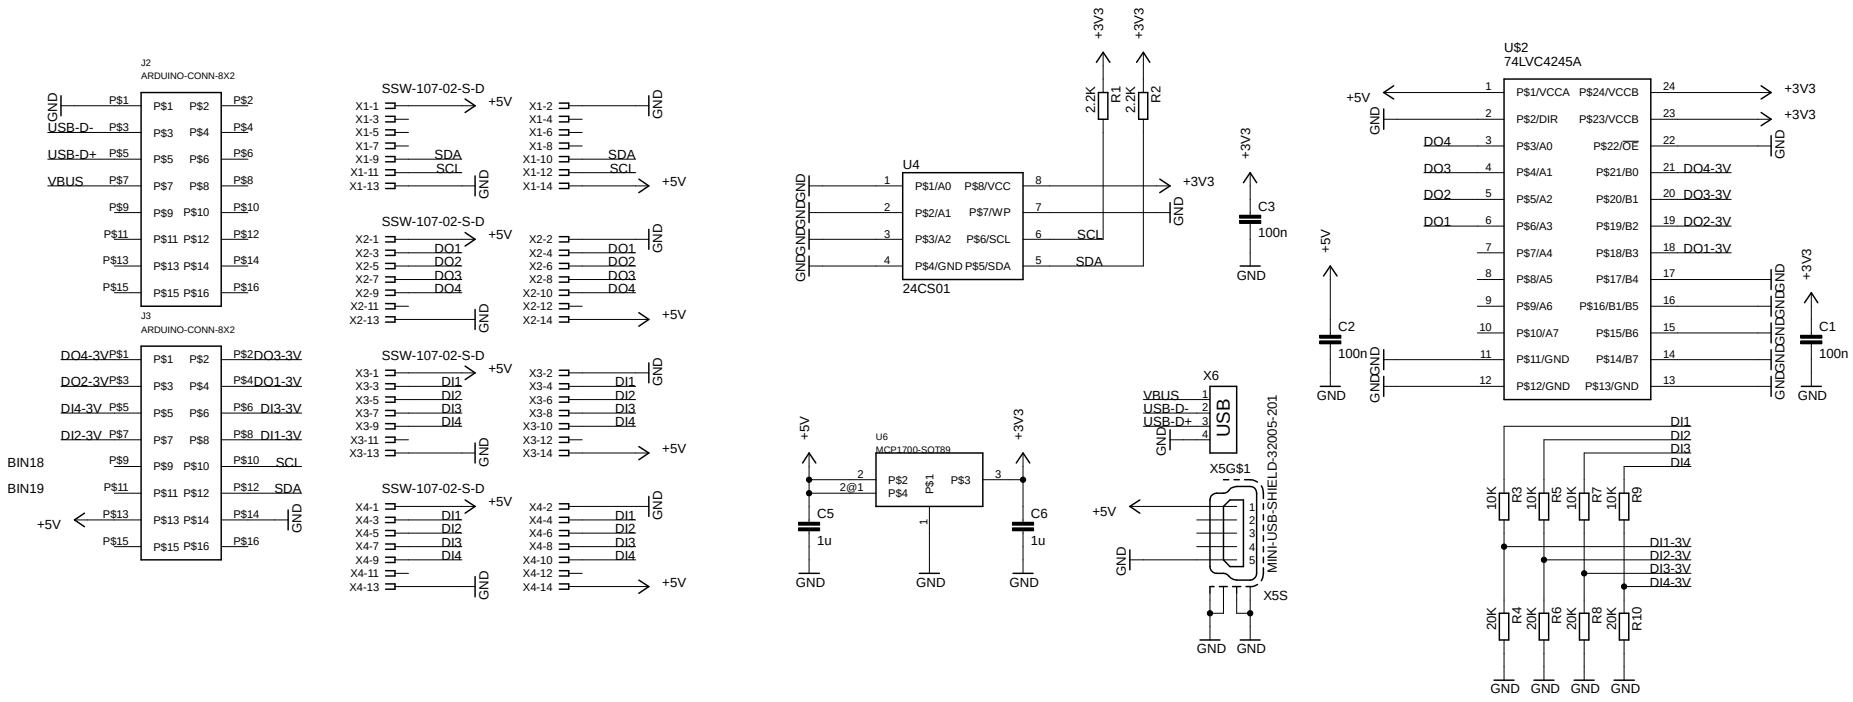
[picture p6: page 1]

6 SCL

GND GND

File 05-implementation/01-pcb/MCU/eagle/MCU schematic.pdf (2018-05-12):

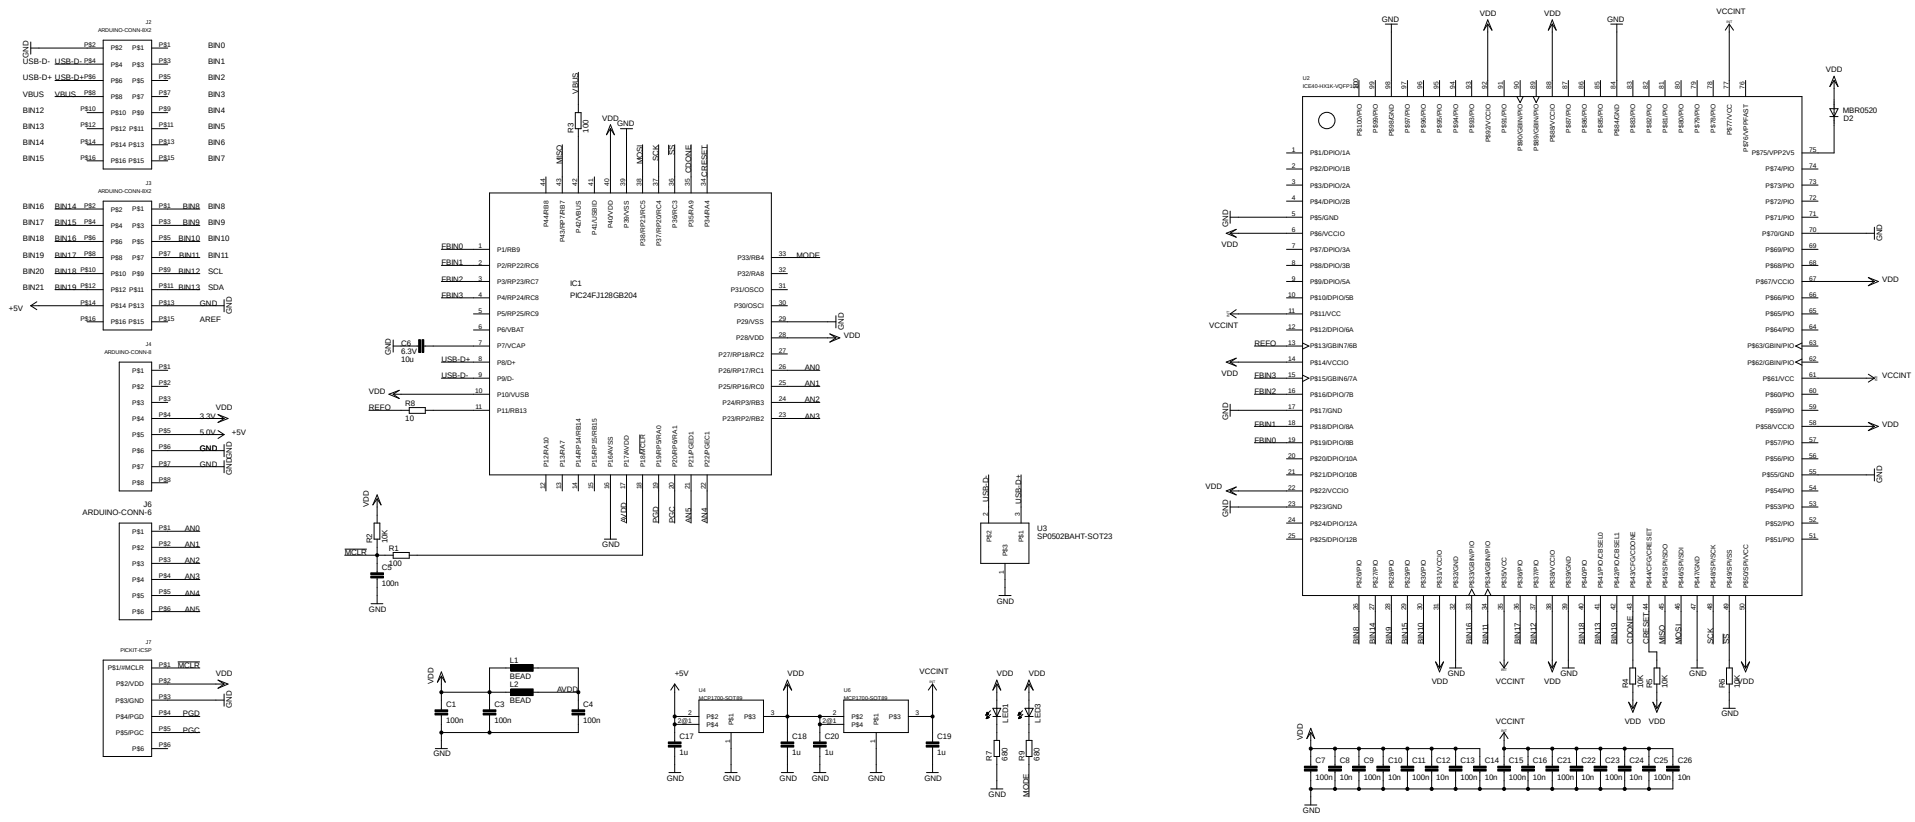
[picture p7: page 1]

GND GND GND VDD

VDD GND GND VCCINT

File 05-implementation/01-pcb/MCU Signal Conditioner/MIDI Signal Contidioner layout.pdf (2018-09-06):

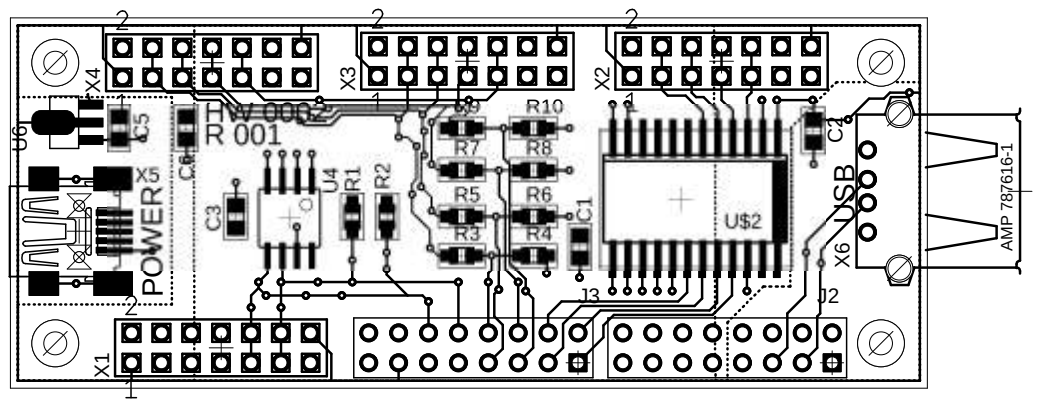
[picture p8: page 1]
AMP 787616-1; POWER; USB

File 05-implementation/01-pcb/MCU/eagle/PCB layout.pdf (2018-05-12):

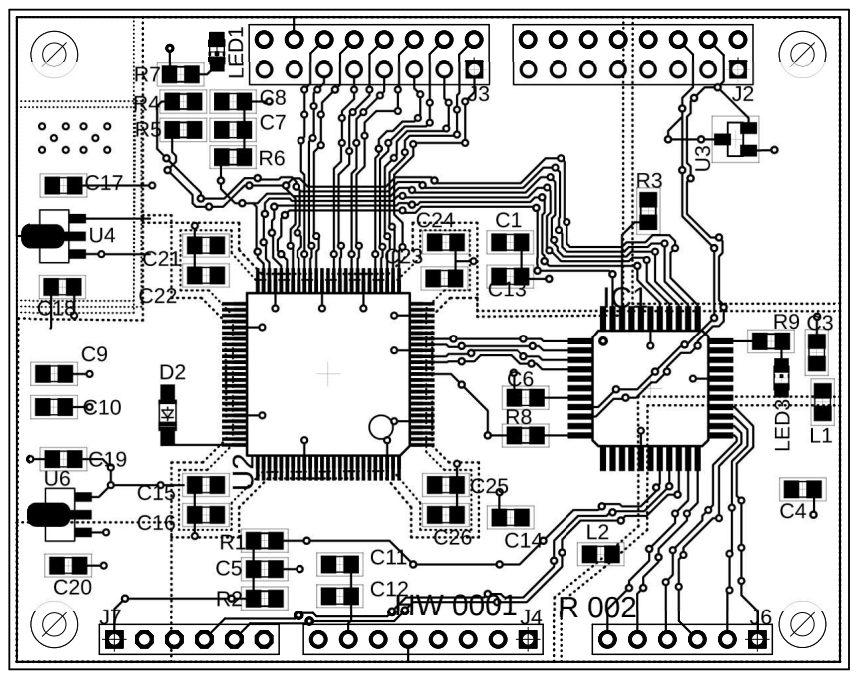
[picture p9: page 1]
J6 LED¹

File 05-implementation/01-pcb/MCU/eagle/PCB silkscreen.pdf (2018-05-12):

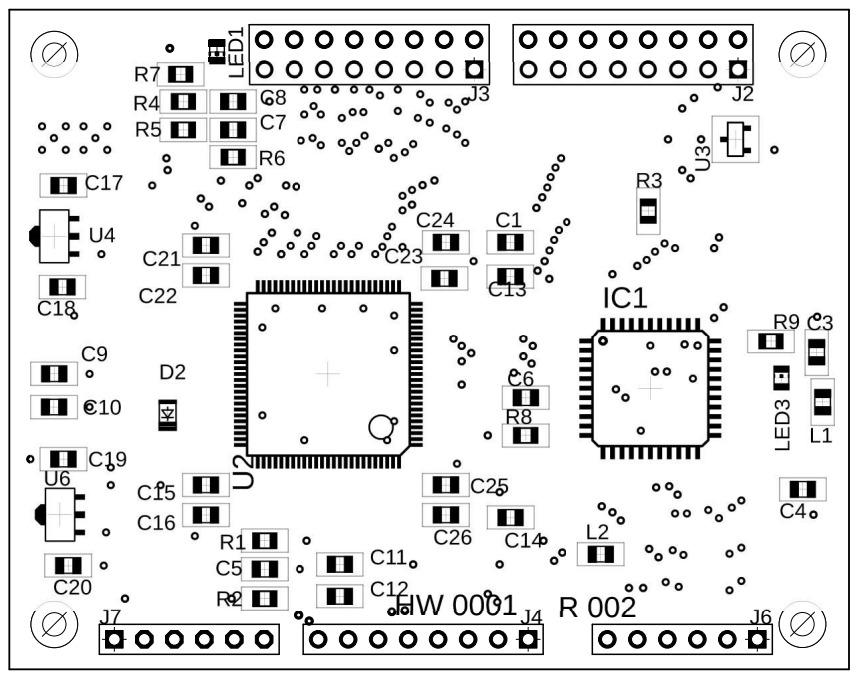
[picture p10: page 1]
J6 LED¹

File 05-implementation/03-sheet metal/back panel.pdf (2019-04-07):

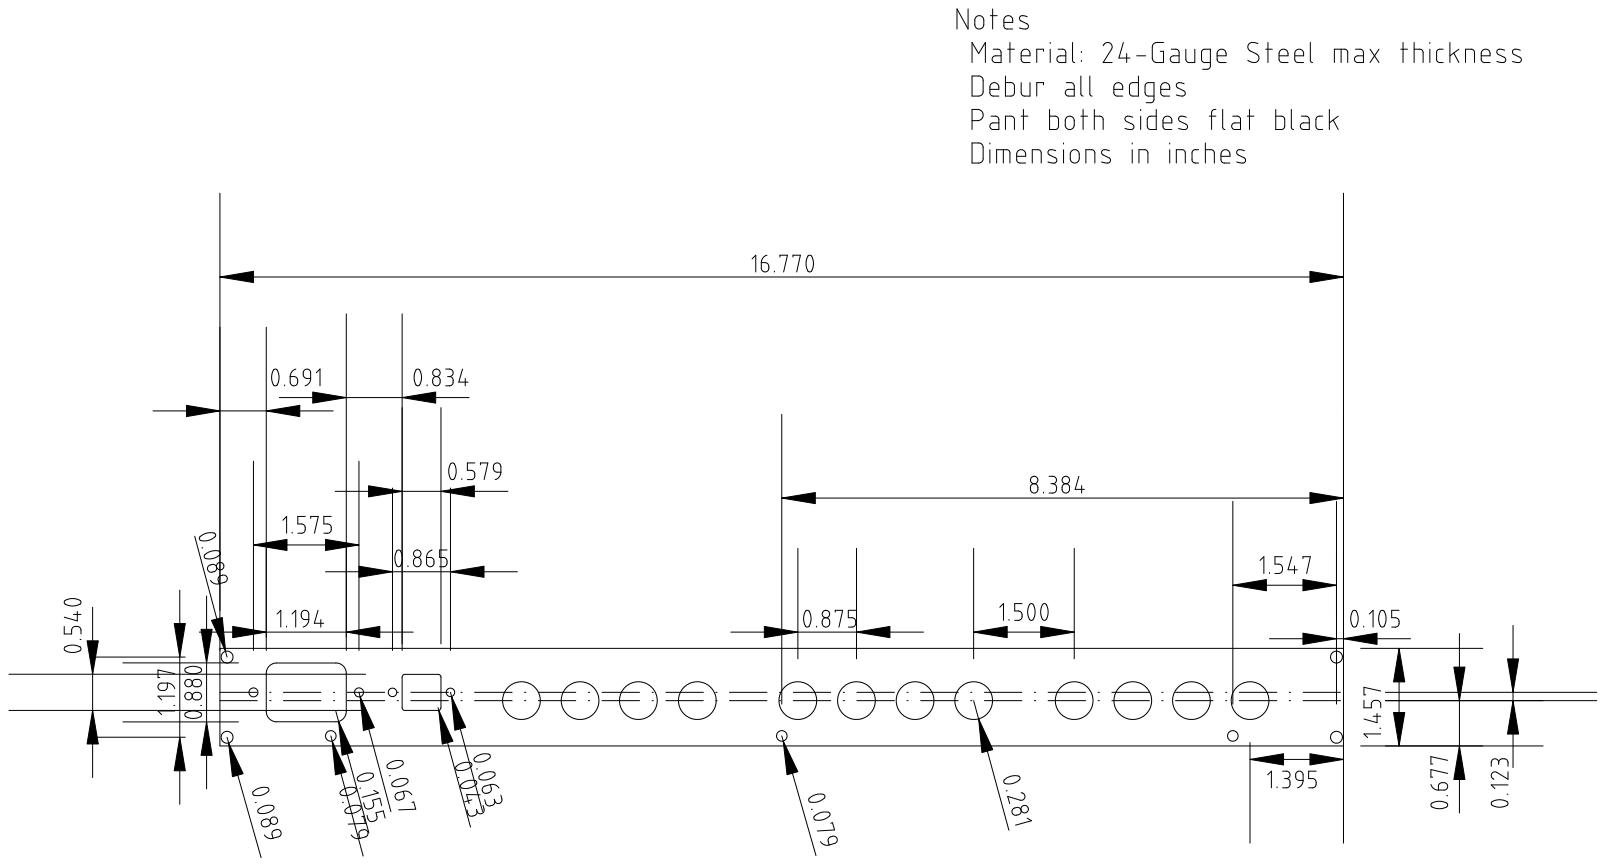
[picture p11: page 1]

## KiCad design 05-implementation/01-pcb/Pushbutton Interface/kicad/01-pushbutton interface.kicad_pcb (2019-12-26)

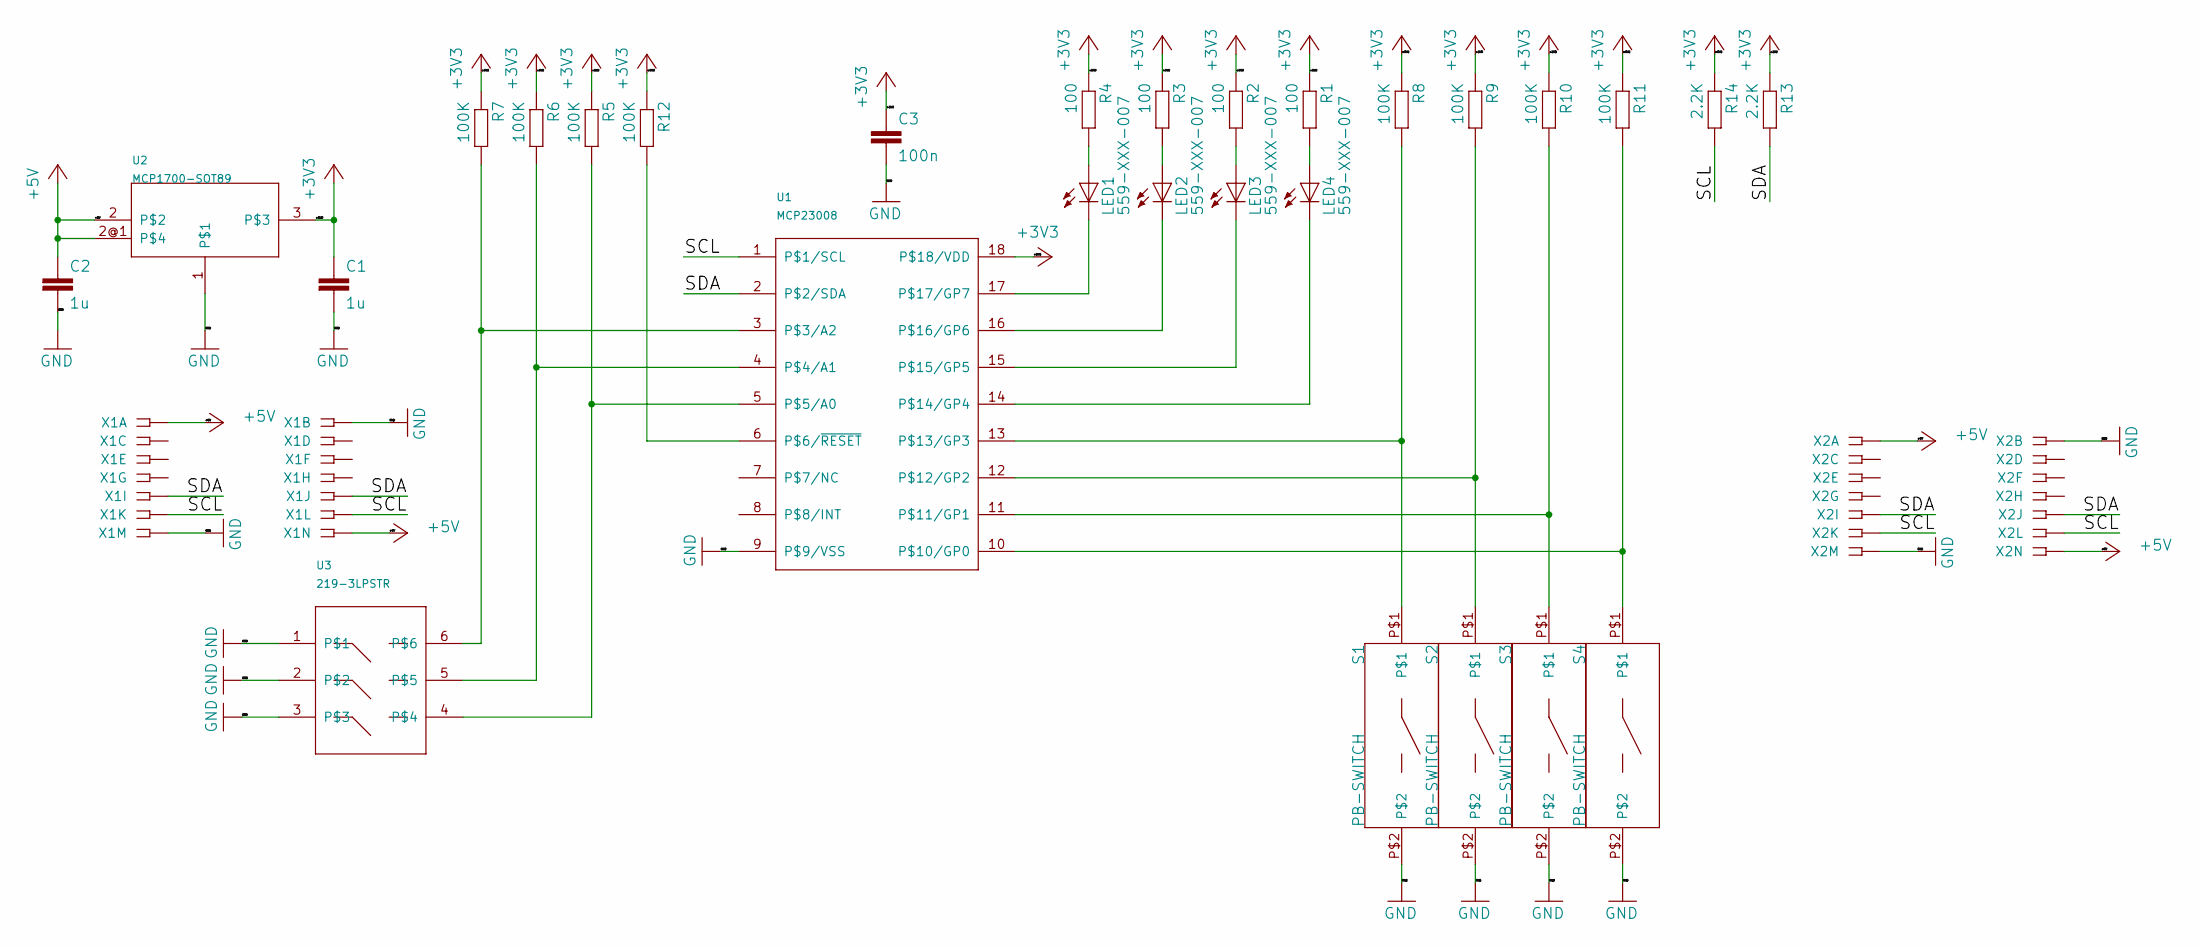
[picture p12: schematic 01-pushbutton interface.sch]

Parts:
C1, C2: 1u; C0805
C3: 100n; C0805
LED1, LED2, LED3, LED4: 559-XXX-007; LED
R1, R2, R3, R4: 100; R0805
R5, R6, R7, R8, R9, R10, R11, R12: 100K; R0805
R13, R14: 2.2K; R0805
S1, S2, S3, S4: PB-SWITCH; SWITCH
U1: MCP23008; MCP23008-SO18
U2: MCP1700-SOT89
U3: 219-3LPSTR
X1, X2: SSW-107-02-G-D

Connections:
+3V3: C1.1, C3.1, R1.1, R2.1, R3.1, R4.1, R5.1, R6.1, R7.1, R8.1, R9.1, R10.1, R11.1, R12.1, R13.1, R14.1, U1.18 (P$18/VDD), U2.3
+5V: C2.1, U2.2, U2.2@1, X1.1, X1.14, X2.1, X2.14
/SCL: R14.2, U1.1 (P$1/SCL), X1.11, X1.12, X2.11, X2.12
/SDA: R13.2, U1.2 (P$2/SDA), X1.9, X1.10, X2.9, X2.10
GND: C1.2, C2.2, C3.2, S1.P$2, S2.P$2, S3.P$2, S4.P$2, U1.9 (P$9/VSS), U2.1, U3.1, U3.2, U3.3, X1.2, X1.13, X2.2, X2.13
unnamed: LED1.P$1 (A), R4.2
unnamed: LED1.P$2 (C), U1.17 (P$17/GP7)
unnamed: LED2.P$1 (A), R3.2
unnamed: LED2.P$2 (C), U1.16 (P$16/GP6)
unnamed: LED3.P$1 (A), R2.2
unnamed: LED3.P$2 (C), U1.15 (P$15/GP5)
unnamed: LED4.P$1 (A), R1.2
unnamed: LED4.P$2 (C), U1.14 (P$14/GP4)
unnamed: R5.2, U1.5 (P$5/A0), U3.4
unnamed: R6.2, U1.4 (P$4/A1), U3.5
unnamed: R7.2, U1.3 (P$3/A2), U3.6
unnamed: R8.2, S1.P$1, U1.13 (P$13/GP3)
unnamed: R9.2, S2.P$1, U1.12 (P$12/GP2)
unnamed: R10.2, S3.P$1, U1.11 (P$11/GP1)
unnamed: R11.2, S4.P$1, U1.10 (P$10/GP0)
unnamed: R12.2, U1.6 (P$6/~RESET)

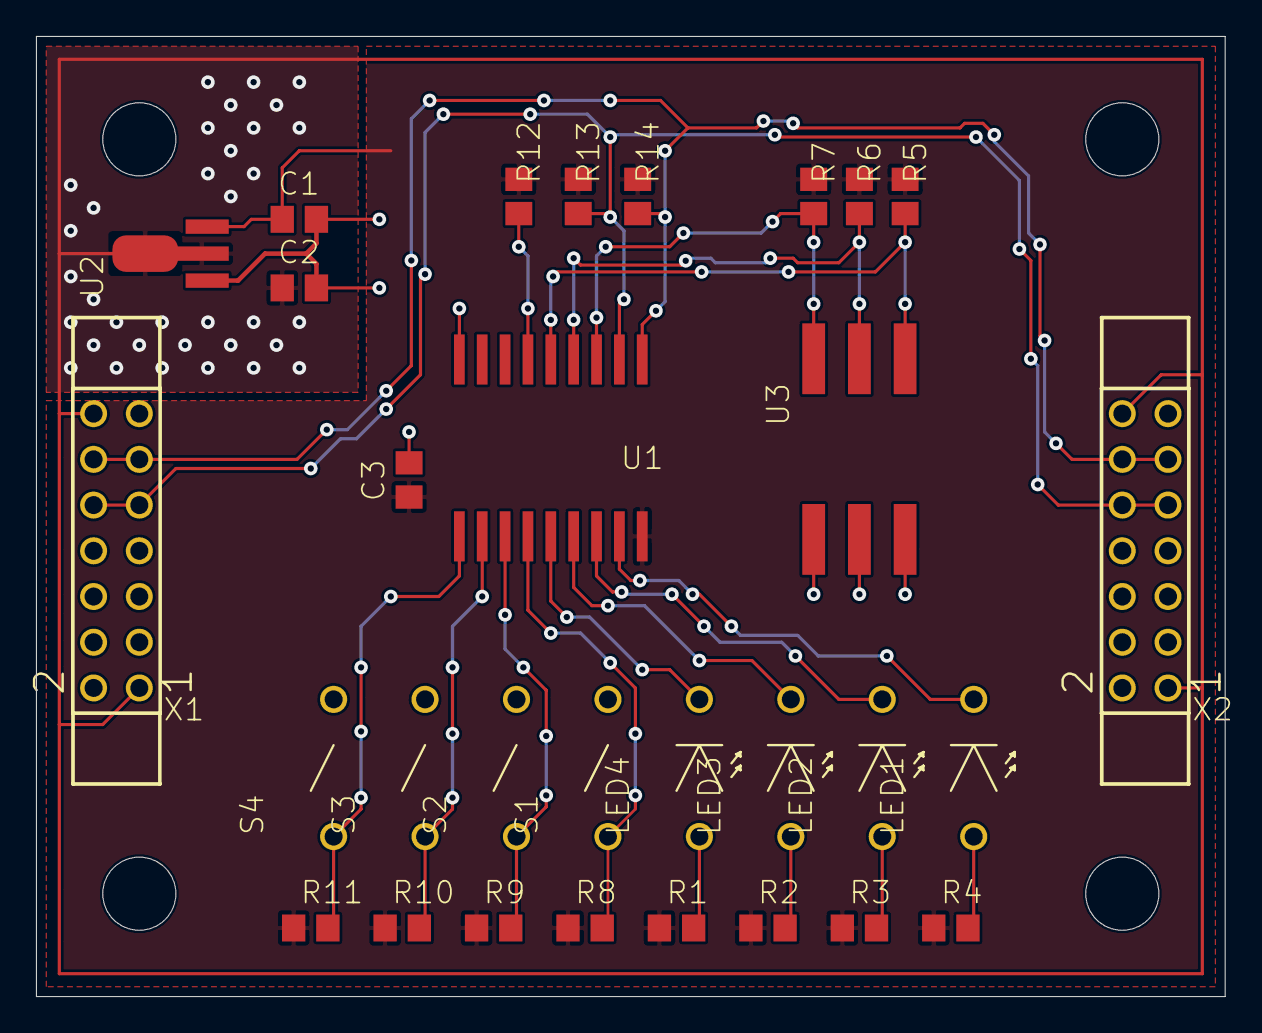
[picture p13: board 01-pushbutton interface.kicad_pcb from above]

Board: 2 copper layers, 66.0 x 53.3 mm, 34 parts (0 on the bottom side), 21 nets.

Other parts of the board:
@HOLE0, @HOLE1, @HOLE2, @HOLE3: (no value)

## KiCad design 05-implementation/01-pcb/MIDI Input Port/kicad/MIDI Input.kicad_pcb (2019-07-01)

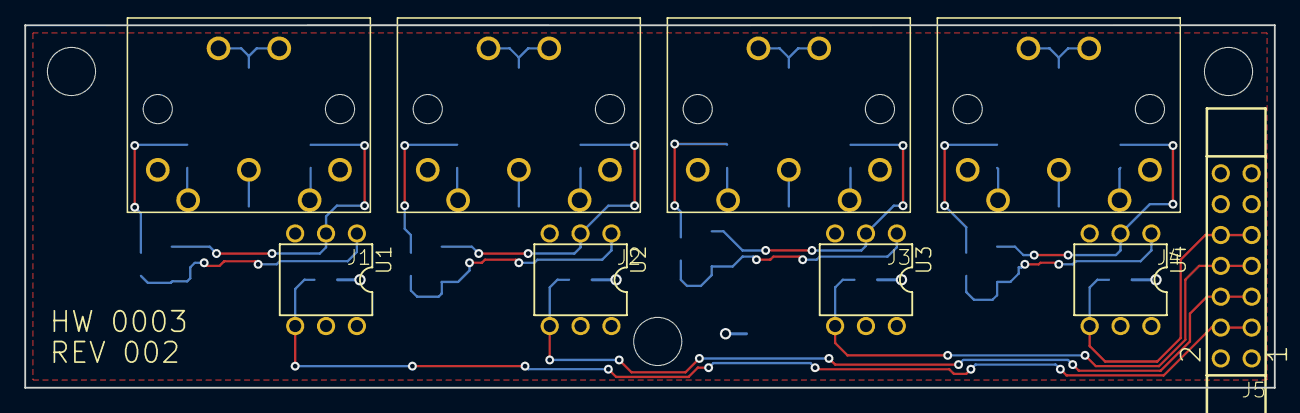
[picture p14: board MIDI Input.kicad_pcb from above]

Board: 2 copper layers, 102.9 x 29.8 mm, 41 parts (0 on the bottom side), 34 nets.

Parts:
@HOLE0, @HOLE1, @HOLE2: (no value)
C1, C2, C3, C4, C5, C6, C7, C8, C9: 100n; C0805
D1, D2, D3, D4: 1N914; SOD323-W
J1, J2, J3, J4: SDS-50J
J5: SSW-107-02-G-D
L1, L2, L3, L4, L5, L6, L7, L8: BEAD; L0805
R1, R3, R5, R7: 220; R0805
R2, R4, R6, R8: 280; R0805
U1, U2, U3, U4: PC900V; DIL06

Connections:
+5V: C9.1, J5.1, J5.14, R2.2, R4.2, R6.2, R8.2, U1.P$6, U2.P$6, U3.P$6, U4.P$6
/D-IN1: J5.3, J5.4, R2.1, U1.P$4
/D-IN2: J5.5, J5.6, R4.1, U2.P$4
/D-IN3: J5.7, J5.8, R6.1, U3.P$4
/D-IN4: J5.9, J5.10, R8.1, U4.P$4
/M-L1: J1.P$5, L2.1
/M-L2: J2.P$5, L4.1
/M-L3: J3.P$5, L6.1
/M-L4: J4.P$5, L8.1
/M-N1: J1.P$4, R1.1
/M-N2: J2.P$4, R3.1
/M-N3: J3.P$4, R5.1
/M-N4: J4.P$4, R7.1
GND: C1.2, C2.2, C3.2, C4.2, C5.2, C6.2, C7.2, C8.2, C9.2, J5.2, J5.13, U1.P$5, U2.P$5, U3.P$5, U4.P$5
unnamed: C1.1, J1.P$2
unnamed: C2.1, J1.P$6, J1.P$7
unnamed: C3.1, J2.P$2
unnamed: C4.1, J2.P$6, J2.P$7
unnamed: C5.1, J3.P$2
unnamed: C6.1, J3.P$6, J3.P$7
unnamed: C7.1, J4.P$2
unnamed: C8.1, J4.P$6, J4.P$7
unnamed: D1.A, L2.2, U1.P$2
unnamed: D1.C, L1.2, U1.P$1
unnamed: D2.A, L4.2, U2.P$2
unnamed: D2.C, L3.2, U2.P$1
unnamed: D3.A, L6.2, U3.P$2
unnamed: D3.C, L5.2, U3.P$1
unnamed: D4.A, L8.2, U4.P$2
unnamed: D4.C, L7.2, U4.P$1
unnamed: L1.1, R1.2
unnamed: L3.1, R3.2
unnamed: L5.1, R5.2
unnamed: L7.1, R7.2

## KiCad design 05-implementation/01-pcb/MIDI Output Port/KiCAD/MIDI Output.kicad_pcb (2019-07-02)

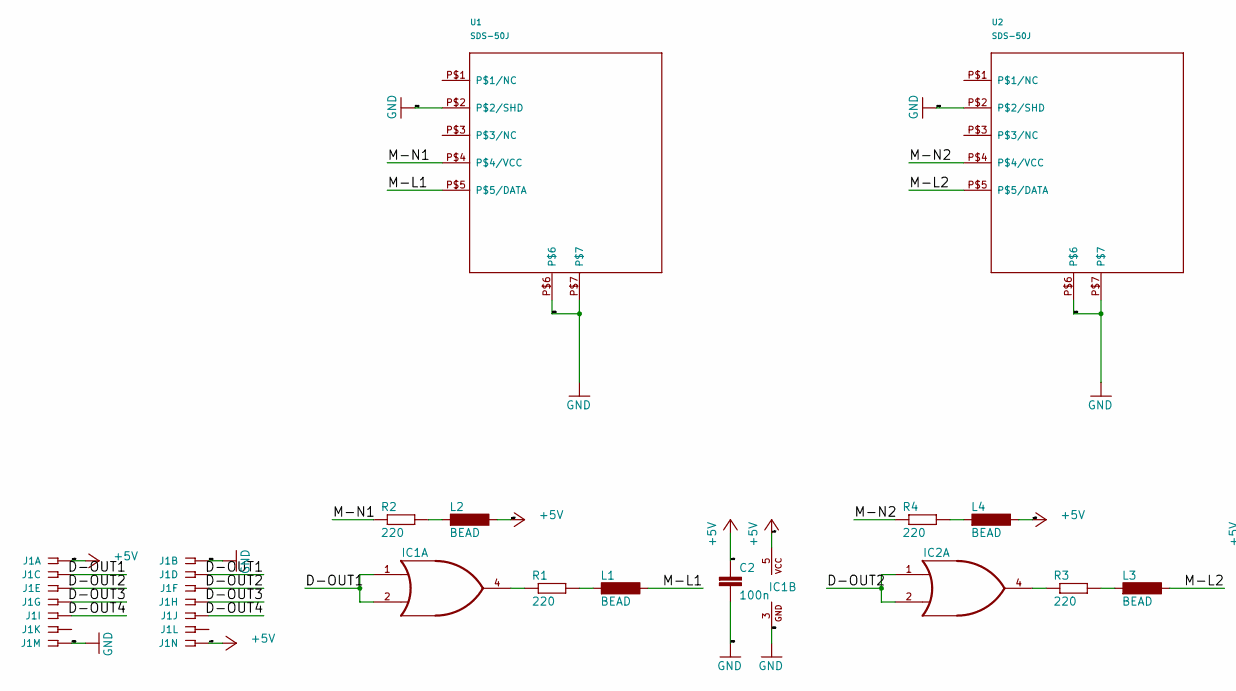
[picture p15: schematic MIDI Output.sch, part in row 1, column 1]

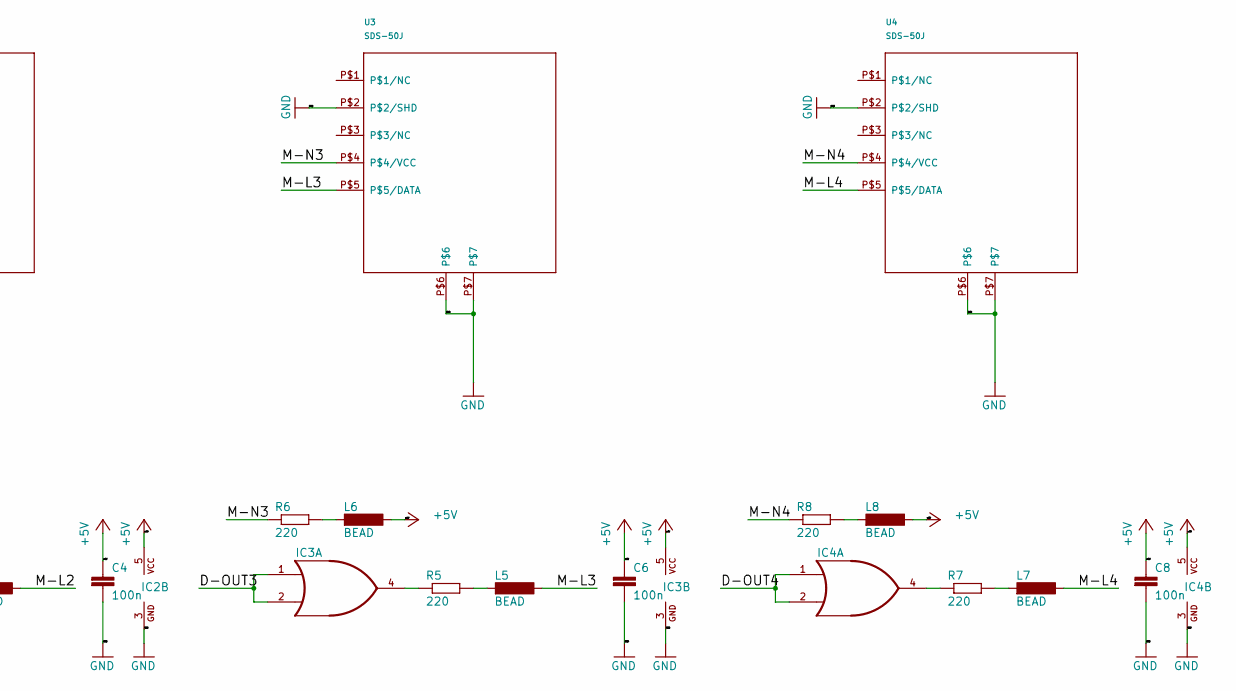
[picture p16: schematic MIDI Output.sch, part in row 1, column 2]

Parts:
C2, C4, C6, C8: 100n; C0805
IC1, IC2, IC3, IC4: 741G32; SOT25
J1: SSW-107-02-G-D
L1, L2, L3, L4, L5, L6, L7, L8: BEAD; L0805
R1, R2, R3, R4, R5, R6, R7, R8: 220; R0805
U1, U2, U3, U4: SDS-50J

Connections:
+5V: C2.1, C4.1, C6.1, C8.1, IC1.5 (VCC), IC2.5 (VCC), IC3.5 (VCC), IC4.5 (VCC), J1.1, J1.14, L2.2, L4.2, L6.2, L8.2
/D-OUT1: IC1.1 (I0), IC1.2 (I1), J1.3, J1.4
/D-OUT2: IC2.1 (I0), IC2.2 (I1), J1.5, J1.6
/D-OUT3: IC3.1 (I0), IC3.2 (I1), J1.7, J1.8
/D-OUT4: IC4.1 (I0), IC4.2 (I1), J1.9, J1.10
/M-L1: L1.2, U1.P$5 (P$5/DATA)
/M-L2: L3.2, U2.P$5 (P$5/DATA)
/M-L3: L5.2, U3.P$5 (P$5/DATA)
/M-L4: L7.2, U4.P$5 (P$5/DATA)
/M-N1: R2.1, U1.P$4 (P$4/VCC)
/M-N2: R4.1, U2.P$4 (P$4/VCC)
/M-N3: R6.1, U3.P$4 (P$4/VCC)
/M-N4: R8.1, U4.P$4 (P$4/VCC)
GND: C2.2, C4.2, C6.2, C8.2, IC1.3 (GND), IC2.3 (GND), IC3.3 (GND), IC4.3 (GND), J1.2, J1.13, U1.P$2 (P$2/SHD), U1.P$6, U1.P$7, U2.P$2 (P$2/SHD), U2.P$6, U2.P$7, U3.P$2 (P$2/SHD), U3.P$6, U3.P$7, U4.P$2 (P$2/SHD), U4.P$6, U4.P$7
unnamed: IC1.4 (O), R1.1
unnamed: IC2.4 (O), R3.1
unnamed: IC3.4 (O), R5.1
unnamed: IC4.4 (O), R7.1
unnamed: L1.1, R1.2
unnamed: L2.1, R2.2
unnamed: L3.1, R3.2
unnamed: L4.1, R4.2
unnamed: L5.1, R5.2
unnamed: L6.1, R6.2
unnamed: L7.1, R7.2
unnamed: L8.1, R8.2

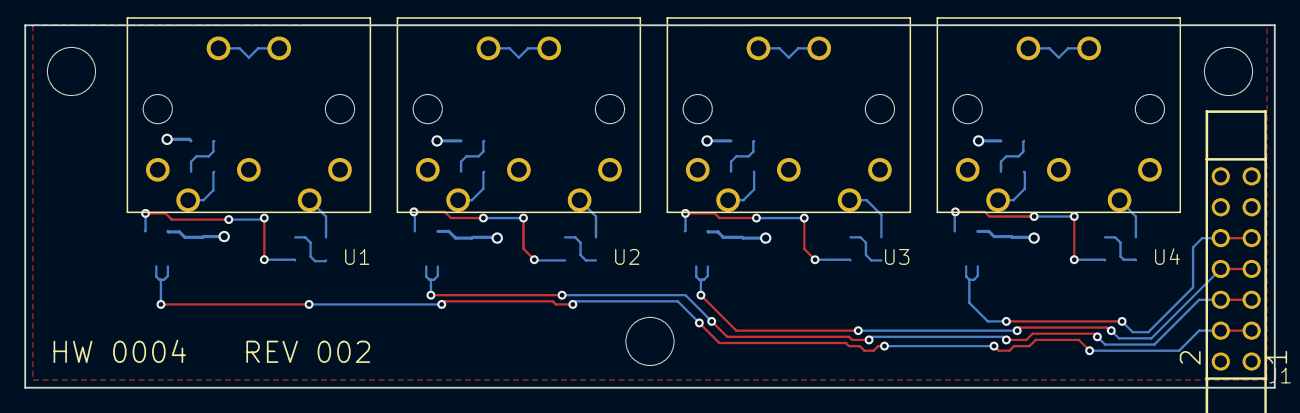
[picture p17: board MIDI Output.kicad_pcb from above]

Board: 2 copper layers, 102.9 x 29.8 mm, 32 parts (0 on the bottom side), 26 nets.

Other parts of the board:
@HOLE0, @HOLE1, @HOLE2: (no value)

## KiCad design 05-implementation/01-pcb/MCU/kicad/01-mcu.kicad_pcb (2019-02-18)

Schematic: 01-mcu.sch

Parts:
C1, C3, C4, C5, C7, C9, C11, C13, C15, C21, C23, C25: 100n; C0805
C6: 10u; C0805
C8, C10, C12, C14, C16, C22, C24, C26: 10n; C0805
C17, C18, C19, C20: 1u; C0805
D2: MBR0520; MBR0520-SOD-123_MINI-SMA
IC1: PIC24FJ128GB204; TQFP44
J2, J3: ARDUINO-CONN-8X2
J4: ARDUINO-CONN-8
J6: ARDUINO-CONN-6
J7: PICKIT-ICSP
L1, L2: BEAD; L0805
LED1, LED3: LEDCHIP-LED0805; CHIP-LED0805
R1, R3: 100; R0805
R2, R4, R5, R6: 10K; R0805
R7, R9: 680; R0805
R8: 10; R0805
U2: ICE40-HX1K-VQFP100; TQFP100-14X14
U3: SP0502BAHT-SOT23; SOT23
U101: MCP1700-1202E_SOT89; SOT-89-3_Handsoldering
U102: MCP1700-3302E_SOT89; SOT-89-3_Handsoldering

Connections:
+5V: C17.1, J3.P$14, J4.P$5, U102.2 (VI)
/AN0: IC1.26, J6.P$1
/AN1: IC1.25, J6.P$2
/AN2: IC1.24, J6.P$3
/AN3: IC1.23, J6.P$4
/AN4: IC1.22, J6.P$5
/AN5: IC1.21, J6.P$6
/AVDD: C4.1, IC1.17, L1.2, L2.2
/BIN8: J3.P$1, U2.26
/BIN9: J3.P$3, U2.28
/BIN10: J3.P$5, U2.30
/BIN11: J3.P$7, U2.34
/BIN12: J3.P$9, U2.37
/BIN13: J3.P$11, U2.41
/BIN14: J3.P$2, U2.27
/BIN15: J3.P$4, U2.29
/BIN16: J3.P$6, U2.33
/BIN17: J3.P$8, U2.36
/BIN18: J3.P$10, U2.40
/BIN19: J3.P$12, U2.42
/CDONE: IC1.35, R4.2, U2.43
/CRESET: IC1.34, R5.2, U2.44
/FBIN0: IC1.1, U2.19
/FBIN1: IC1.2, U2.18
/FBIN2: IC1.3, U2.16
/FBIN3: IC1.4, U2.15
/MISO: IC1.43, U2.45
/MODE: IC1.33, R9.1
/MOSI: IC1.38, U2.46
/PGC: IC1.20, J7.P$5
/PGD: IC1.19, J7.P$4
/REFO: R8.1, U2.13
/SCK: IC1.37, U2.48
/USB-D+: IC1.8, J2.P$6, U3.3
/USB-D-: IC1.9, J2.P$4, U3.2
/VBUS: J2.P$8, R3.2
/~MCLR: C5.1, J7.P$1, R1.1, R2.1
/~SS: IC1.36, R6.2, U2.49
GND: C1.2, C3.2, C4.2, C5.2, C6.1, C7.2, C8.2, C9.2, C10.2, C11.2, C12.2, C13.2, C14.2, C15.2, C16.2, C17.2, C18.2, C19.2, C20.2, C21.2, C22.2, C23.2, C24.2, C25.2, C26.2, IC1.16, IC1.29, IC1.39, J2.P$2, J3.P$13, J4.P$6, J4.P$7, J7.P$3, R6.1, R7.1, U2.5, U2.17, U2.23, U2.32, U2.39, U2.47, U2.55, U2.70, U2.84, U2.98, U3.1, U101.1 (GND), U102.1 (GND)
unnamed: C6.2, IC1.7
unnamed: D2.C, U2.75
unnamed: IC1.11, R8.2
unnamed: IC1.18, R1.2
unnamed: IC1.42, R3.1
unnamed: LED1.C, R7.2
unnamed: LED3.C, R9.2
VCCINT: C15.1, C16.1, C19.1, C21.1, C22.1, C23.1, C24.1, C25.1, C26.1, U2.11, U2.35, U2.61, U2.77, U101.3 (VO)
VDD: C1.1, C3.1, C7.1, C8.1, C9.1, C10.1, C11.1, C12.1, C13.1, C14.1, C18.1, C20.1, D2.A, IC1.10, IC1.28, IC1.40, J4.P$4, J7.P$2, L1.1, L2.1, LED1.A, LED3.A, R2.2, R4.1, R5.1, U2.6, U2.14, U2.22, U2.31, U2.38, U2.50, U2.58, U2.67, U2.88, U2.92, U101.2 (VI), U102.3 (VO)

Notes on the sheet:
3.3V
5.0V
GND
AREF
BIN0
BIN1
BIN2
BIN3
BIN4
BIN5
BIN6
BIN7
USB-D-
USB-D+
VBUS
BIN12
BIN13
BIN14
BIN15
BIN8
BIN9
BIN10
BIN11
SCL
SDA
BIN16
BIN17
BIN18
BIN19
BIN20
BIN21

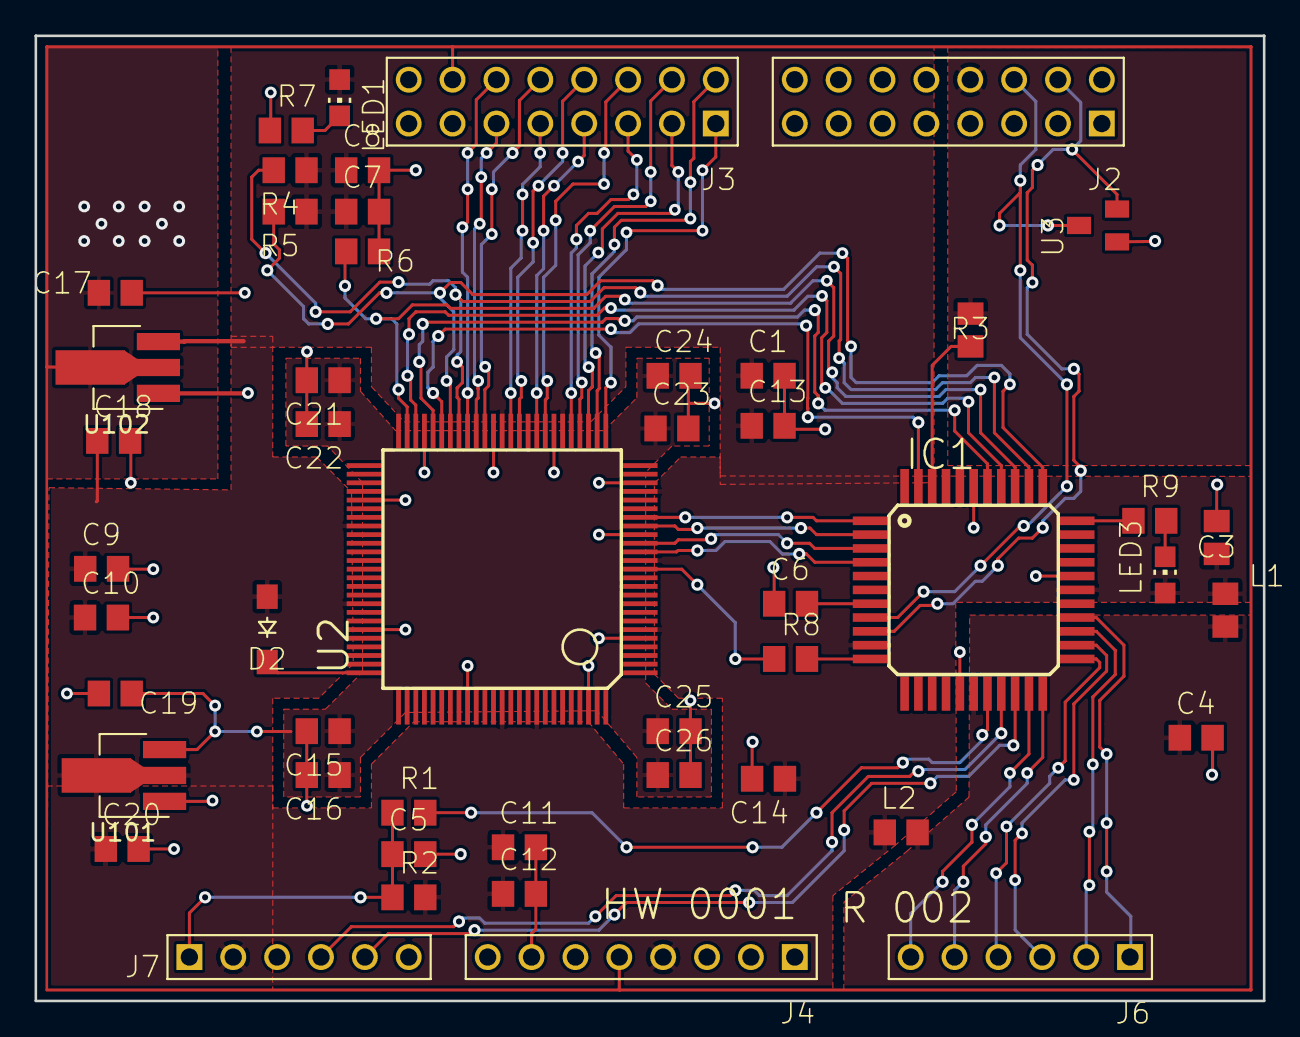
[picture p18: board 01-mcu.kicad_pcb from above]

Board: 2 copper layers, 71.1 x 55.9 mm, 49 parts (0 on the bottom side), 48 nets.

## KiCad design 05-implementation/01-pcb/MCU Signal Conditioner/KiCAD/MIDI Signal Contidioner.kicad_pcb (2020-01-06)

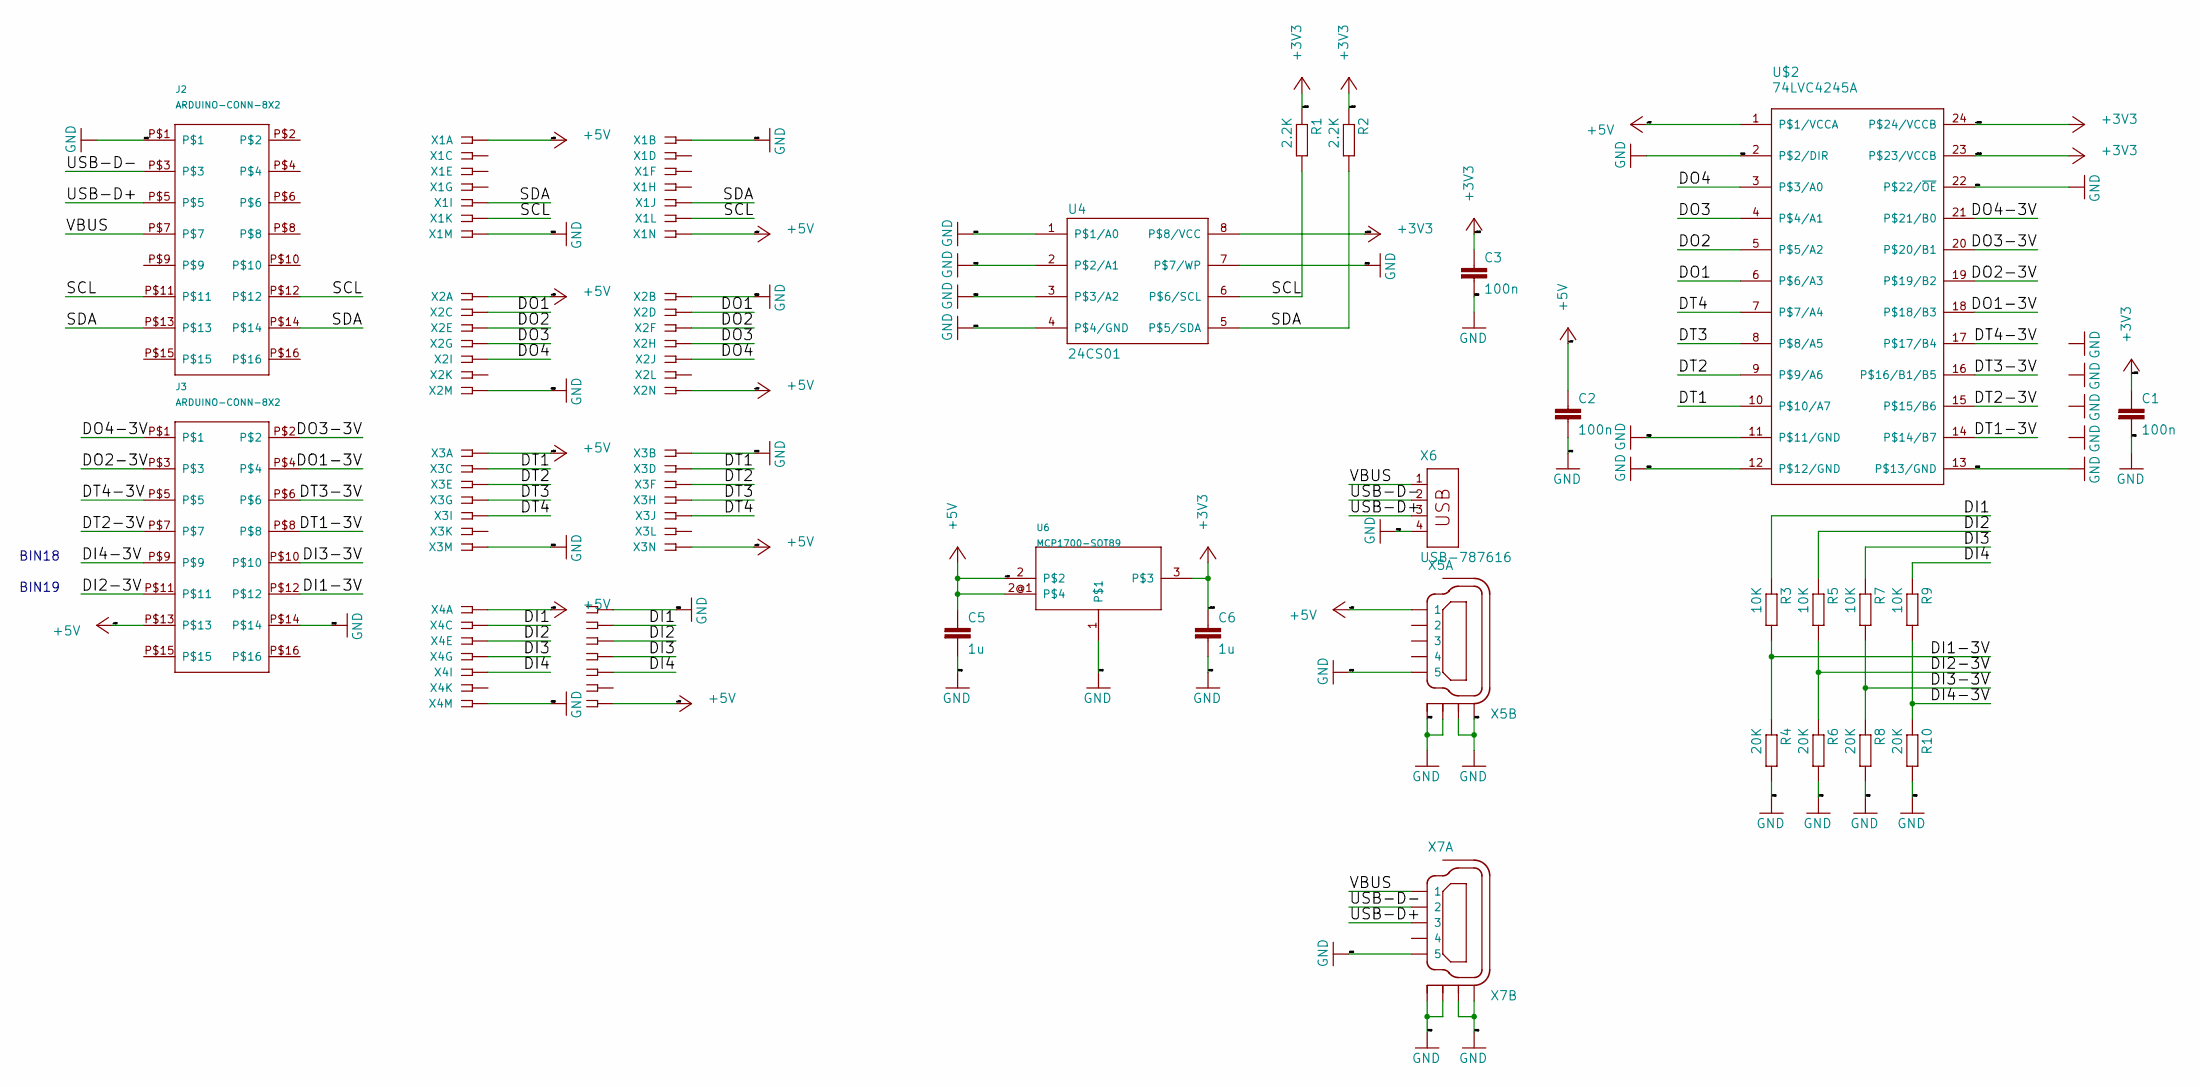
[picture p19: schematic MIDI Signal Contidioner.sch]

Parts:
C1, C2, C3: 100n; C0805
C5, C6: 1u; C0805
J2, J3: ARDUINO-CONN-8X2
R1, R2: 2.2K; R0805W
R3, R5, R7, R9: 10K; R0805W
R4, R6, R8, R10: 20K; R0805W
U4: 24CS01; 24CS01-SO8
U6: MCP1700-SOT89
U$2: 74LVC4245A; 74LVC4245A-SO24
X1, X2, X3, X4: SSW-107-02-G-D
X5, X7: MINI-USB-SHIELD-32005-201; MINI-USB-32005-201
X6: USB-787616; USB

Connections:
+3V3: C1.1, C3.1, C6.1, R1.1, R2.1, U4.8 (P$8/VCC), U6.3, U$2.23 (P$23/VCCB), U$2.24 (P$24/VCCB)
+5V: C2.1, C5.1, J3.P$13, U6.2, U6.2@1, U$2.1 (P$1/VCCA), X1.1, X1.14, X2.1, X2.14, X3.1, X3.14, X4.1, X4.14, X5.1
/DI1: R3.1, X4.3, X4.4
/DI1-3V: J3.P$12, R3.2, R4.1
/DI2: R5.1, X4.5, X4.6
/DI2-3V: J3.P$11, R5.2, R6.1
/DI3: R7.1, X4.7, X4.8
/DI3-3V: J3.P$10, R7.2, R8.1
/DI4: R9.1, X4.9, X4.10
/DI4-3V: J3.P$9, R9.2, R10.1
/DO1: U$2.6 (P$6/A3), X2.3, X2.4
/DO1-3V: J3.P$4, U$2.18 (P$18/B3)
/DO2: U$2.5 (P$5/A2), X2.5, X2.6
/DO2-3V: J3.P$3, U$2.19 (P$19/B2)
/DO3: U$2.4 (P$4/A1), X2.7, X2.8
/DO3-3V: J3.P$2, U$2.20 (P$20/B1)
/DO4: U$2.3 (P$3/A0), X2.9, X2.10
/DO4-3V: J3.P$1, U$2.21 (P$21/B0)
/DT1: U$2.10 (P$10/A7), X3.3, X3.4
/DT1-3V: J3.P$8, U$2.14 (P$14/B7)
/DT2: U$2.9 (P$9/A6), X3.5, X3.6
/DT2-3V: J3.P$7, U$2.15 (P$15/B6)
/DT3: U$2.8 (P$8/A5), X3.7, X3.8
/DT3-3V: J3.P$6, U$2.16 (P$16/B1/B5)
/DT4: U$2.7 (P$7/A4), X3.9, X3.10
/DT4-3V: J3.P$5, U$2.17 (P$17/B4)
/SCL: J2.P$11, J2.P$12, R1.2, U4.6 (P$6/SCL), X1.11, X1.12
/SDA: J2.P$13, J2.P$14, R2.2, U4.5 (P$5/SDA), X1.9, X1.10
/USB-D+: J2.P$5, X6.3, X7.3
/USB-D-: J2.P$3, X6.2, X7.2
/VBUS: J2.P$7, X6.1, X7.1
GND: C1.2, C2.2, C3.2, C5.2, C6.2, J2.P$1, J3.P$14, R4.2, R6.2, R8.2, R10.2, U4.1 (P$1/A0), U4.2 (P$2/A1), U4.3 (P$3/A2), U4.4 (P$4/GND), U4.7 (P$7/WP), U6.1, U$2.2 (P$2/DIR), U$2.11 (P$11/GND), U$2.12 (P$12/GND), U$2.13 (P$13/GND), U$2.22 (P$22/~OE), X1.2, X1.13, X2.2, X2.13, X3.2, X3.13, X4.2, X4.13, X5.5, X5.M1 (S1), X5.M2 (S2), X5.M3 (S3), X5.M4 (S4), X6.4, X7.5, X7.M1 (S1), X7.M2 (S2), X7.M3 (S3), X7.M4 (S4)

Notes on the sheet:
BIN18
BIN19

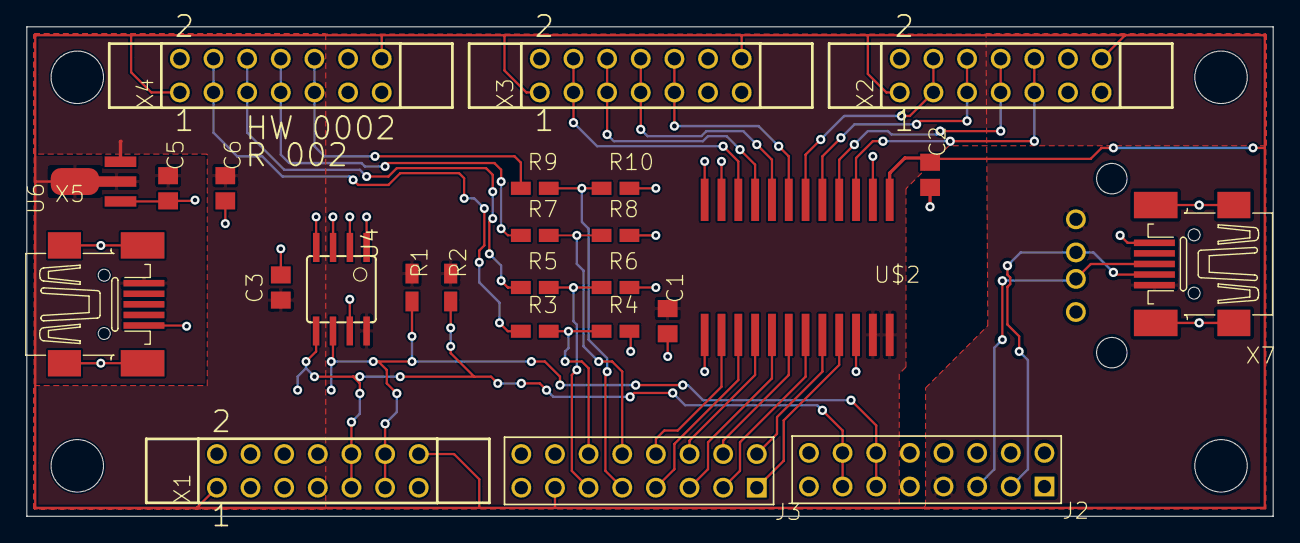
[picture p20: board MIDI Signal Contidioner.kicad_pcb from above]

Board: 2 copper layers, 94.1 x 37.0 mm, 31 parts (0 on the bottom side), 32 nets.

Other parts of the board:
@HOLE0, @HOLE1, @HOLE2, @HOLE3: (no value)

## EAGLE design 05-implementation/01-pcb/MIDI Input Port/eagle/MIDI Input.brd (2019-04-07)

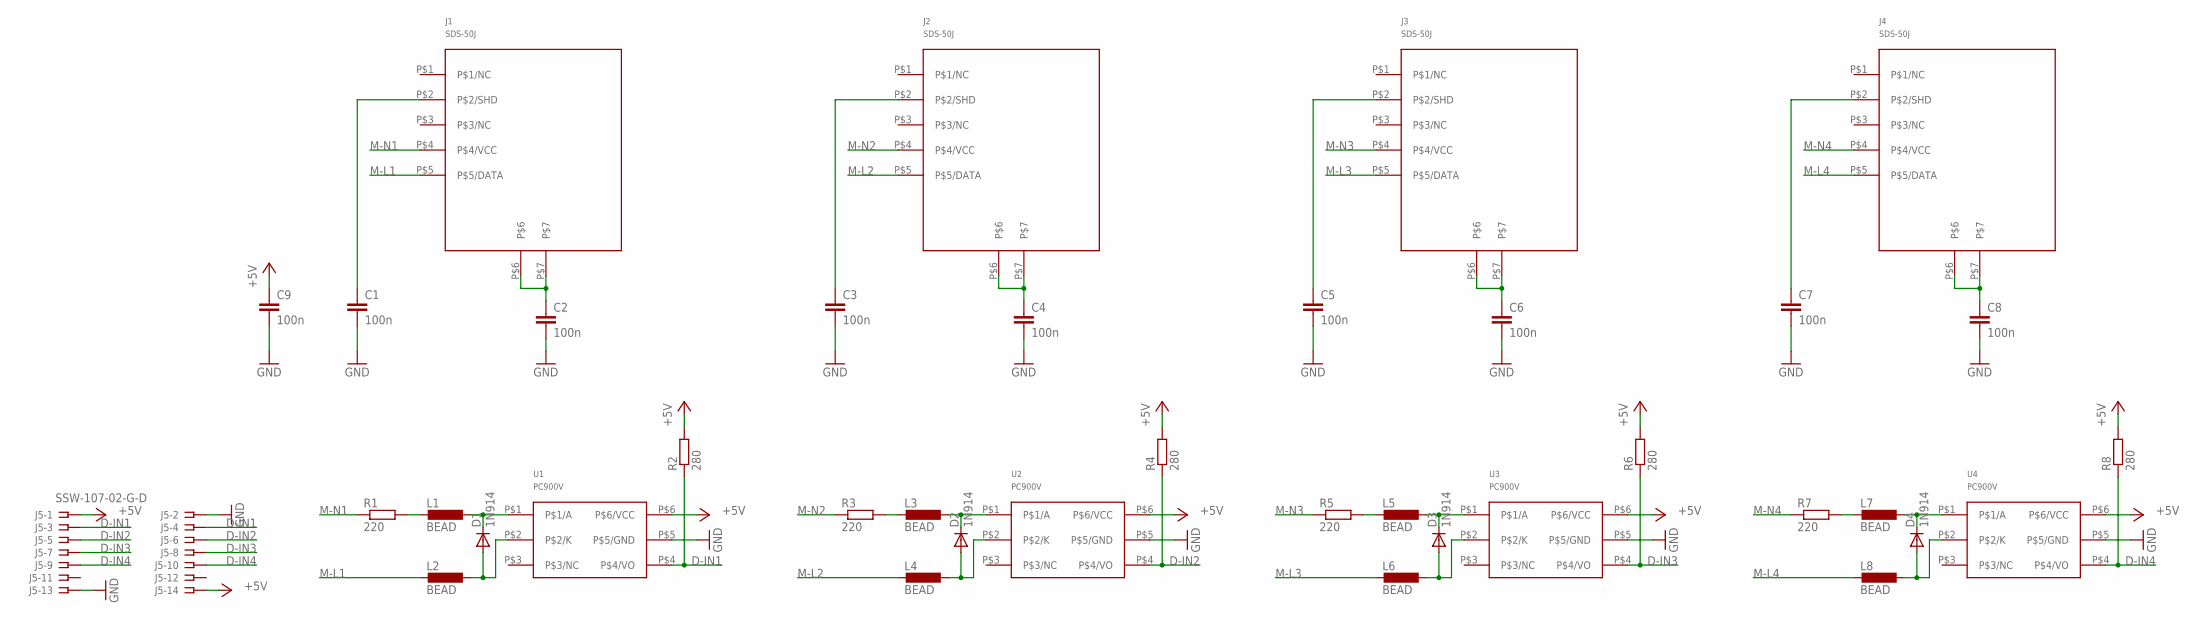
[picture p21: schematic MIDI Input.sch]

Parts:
C1, C2, C3, C4, C5, C6, C7, C8, C9: 100n; C0805
D1, D2, D3, D4: 1N914; SOD323-W
J1, J2, J3, J4: SDS-50J
J5: SSW-107-02-G-D
L1, L2, L3, L4, L5, L6, L7, L8: BEAD; L0805
R1, R3, R5, R7: 220; R0805
R2, R4, R6, R8: 280; R0805
U1, U2, U3, U4: PC900V; DIL06

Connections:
+5V: C9.1, J5.1, J5.14, R2.2, R4.2, R6.2, R8.2, U1.P$6 (P$6/VCC), U2.P$6 (P$6/VCC), U3.P$6 (P$6/VCC), U4.P$6 (P$6/VCC)
D-IN1: J5.3, J5.4, R2.1, U1.P$4 (P$4/VO)
D-IN2: J5.5, J5.6, R4.1, U2.P$4 (P$4/VO)
D-IN3: J5.7, J5.8, R6.1, U3.P$4 (P$4/VO)
D-IN4: J5.9, J5.10, R8.1, U4.P$4 (P$4/VO)
GND: C1.2, C2.2, C3.2, C4.2, C5.2, C6.2, C7.2, C8.2, C9.2, J5.2, J5.13, U1.P$5 (P$5/GND), U2.P$5 (P$5/GND), U3.P$5 (P$5/GND), U4.P$5 (P$5/GND)
M-L1: J1.P$5 (P$5/DATA), L2.1
M-L2: J2.P$5 (P$5/DATA), L4.1
M-L3: J3.P$5 (P$5/DATA), L6.1
M-L4: J4.P$5 (P$5/DATA), L8.1
M-N1: J1.P$4 (P$4/VCC), R1.1
M-N2: J2.P$4 (P$4/VCC), R3.1
M-N3: J3.P$4 (P$4/VCC), R5.1
M-N4: J4.P$4 (P$4/VCC), R7.1
unnamed: L1.1, R1.2
unnamed: D1.C, L1.2, U1.P$1 (P$1/A)
unnamed: D1.A, L2.2, U1.P$2 (P$2/K)
unnamed: D2.C, L3.2, U2.P$1 (P$1/A)
unnamed: C2.1, J1.P$6, J1.P$7
unnamed: D2.A, L4.2, U2.P$2 (P$2/K)
unnamed: C4.1, J2.P$6, J2.P$7
unnamed: C1.1, J1.P$2 (P$2/SHD)
unnamed: C3.1, J2.P$2 (P$2/SHD)
unnamed: L3.1, R3.2
unnamed: D3.C, L5.2, U3.P$1 (P$1/A)
unnamed: D3.A, L6.2, U3.P$2 (P$2/K)
unnamed: C6.1, J3.P$6, J3.P$7
unnamed: C5.1, J3.P$2 (P$2/SHD)
unnamed: L5.1, R5.2
unnamed: D4.C, L7.2, U4.P$1 (P$1/A)
unnamed: D4.A, L8.2, U4.P$2 (P$2/K)
unnamed: C8.1, J4.P$6, J4.P$7
unnamed: C7.1, J4.P$2 (P$2/SHD)
unnamed: L7.1, R7.2

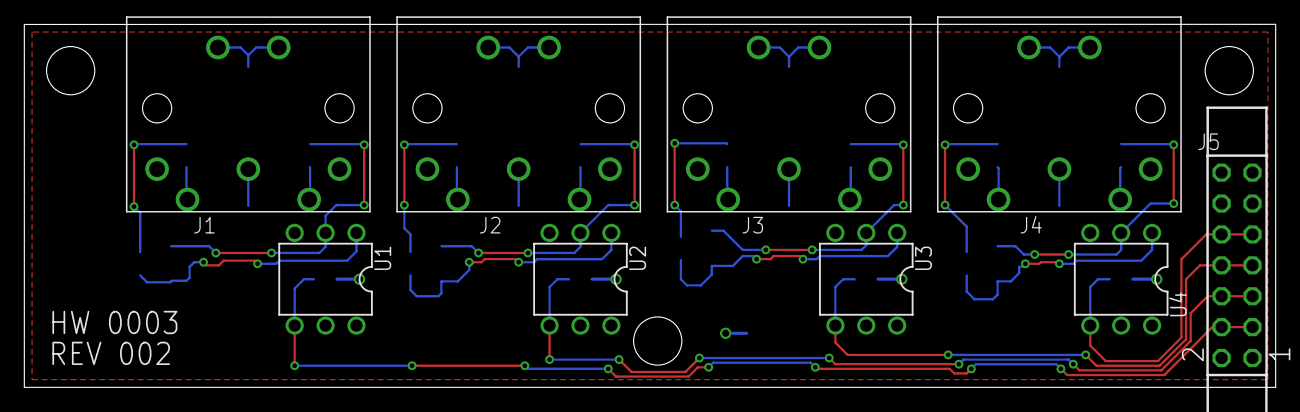
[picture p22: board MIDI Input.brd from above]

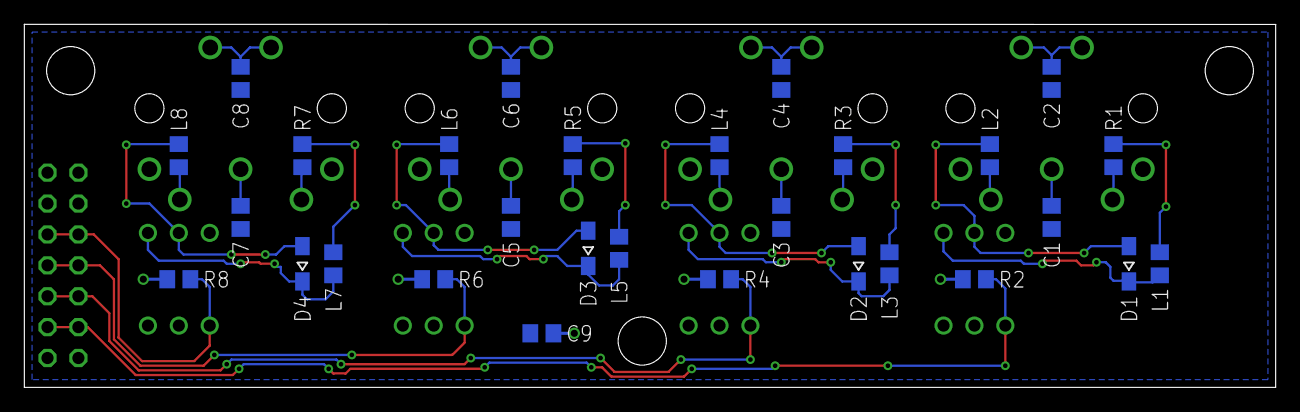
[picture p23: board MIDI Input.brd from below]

Board: 2 copper layers, 102.9 x 29.8 mm, 38 parts (29 on the bottom side), 34 nets.

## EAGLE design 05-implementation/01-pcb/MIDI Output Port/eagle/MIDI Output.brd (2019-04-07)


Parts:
C2, C4, C6, C8: 100n; C0805
IC1, IC2, IC3, IC4: 741G32; SOT25
J1: SSW-107-02-G-D
L1, L2, L3, L4, L5, L6, L7, L8: BEAD; L0805
R1, R2, R3, R4, R5, R6, R7, R8: 220; R0805
U1, U2, U3, U4: SDS-50J

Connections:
+5V: C2.1, C4.1, C6.1, C8.1, IC1.5 (VCC), IC2.5 (VCC), IC3.5 (VCC), IC4.5 (VCC), J1.1, J1.14, L2.2, L4.2, L6.2, L8.2
D-OUT1: IC1.1 (I0), IC1.2 (I1), J1.3, J1.4
D-OUT2: IC2.1 (I0), IC2.2 (I1), J1.5, J1.6
D-OUT3: IC3.1 (I0), IC3.2 (I1), J1.7, J1.8
D-OUT4: IC4.1 (I0), IC4.2 (I1), J1.9, J1.10
GND: C2.2, C4.2, C6.2, C8.2, IC1.3 (GND), IC2.3 (GND), IC3.3 (GND), IC4.3 (GND), J1.2, J1.13, U1.P$2 (P$2/SHD), U1.P$6, U1.P$7, U2.P$2 (P$2/SHD), U2.P$6, U2.P$7, U3.P$2 (P$2/SHD), U3.P$6, U3.P$7, U4.P$2 (P$2/SHD), U4.P$6, U4.P$7
M-L1: L1.2, U1.P$5 (P$5/DATA)
M-L2: L3.2, U2.P$5 (P$5/DATA)
M-L3: L5.2, U3.P$5 (P$5/DATA)
M-L4: L7.2, U4.P$5 (P$5/DATA)
M-N1: R2.1, U1.P$4 (P$4/VCC)
M-N2: R4.1, U2.P$4 (P$4/VCC)
M-N3: R6.1, U3.P$4 (P$4/VCC)
M-N4: R8.1, U4.P$4 (P$4/VCC)
unnamed: IC1.4 (O), R1.1
unnamed: L2.1, R2.2
unnamed: L1.1, R1.2
unnamed: L3.1, R3.2
unnamed: L4.1, R4.2
unnamed: IC2.4 (O), R3.1
unnamed: L5.1, R5.2
unnamed: L6.1, R6.2
unnamed: IC3.4 (O), R5.1
unnamed: L7.1, R7.2
unnamed: L8.1, R8.2
unnamed: IC4.4 (O), R7.1



Board: 2 copper layers, 102.9 x 29.8 mm, 29 parts (24 on the bottom side), 26 nets.

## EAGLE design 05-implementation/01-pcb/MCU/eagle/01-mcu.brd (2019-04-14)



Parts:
C1, C3, C4, C5, C7, C9, C11, C13, C15, C21, C23, C25: 100n; C0805
C6: 10u; C0805; RATING 6.3V
C8, C10, C12, C14, C16, C22, C24, C26: 10n; C0805
C17, C18, C19, C20: 1u; C0805
D2: MBR0520; MBR0520-SOD-123_MINI-SMA
IC1: PIC24FJ128GB204; TQFP44
J2, J3: ARDUINO-CONN-8X2
J4: ARDUINO-CONN-8
J6: ARDUINO-CONN-6
J7: PICKIT-ICSP
L1, L2: BEAD; L0805
LED1, LED3: LEDCHIP-LED0805; CHIP-LED0805
R1, R3: 100; R0805
R2, R4, R5, R6: 10K; R0805
R7, R9: 680; R0805
R8: 10; R0805
U2: ICE40-HX1K-VQFP100; TQFP100-14X14
U3: SP0502BAHT-SOT23; SOT23
U4, U6: MCP1700-SOT89

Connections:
!MCLR: C5.1, J7.P$1 (P$1/#MCLR), R1.1, R2.1
!SS: IC1.36 (P36/RC3), R6.2, U2.49 (P$49/SPI/SS)
+5V: C17.1, J3.P$14, J4.P$5, U4.2, U4.2@1
AN0: IC1.26 (P26/RP17/RC1), J6.P$1
AN1: IC1.25 (P25/RP16/RC0), J6.P$2
AN2: IC1.24 (P24/RP3/RB3), J6.P$3
AN3: IC1.23 (P23/RP2/RB2), J6.P$4
AN4: IC1.22 (P22/PGEC1), J6.P$5
AN5: IC1.21 (P21/PGED1), J6.P$6
AVDD: C4.1, IC1.17 (P17/AVDD), L1.2, L2.2
BIN8: J3.P$1, U2.26 (P$26/PIO)
BIN9: J3.P$3, U2.28 (P$28/PIO)
BIN10: J3.P$5, U2.30 (P$30/PIO)
BIN11: J3.P$7, U2.34 (P$34/GBIN/PIO)
BIN12: J3.P$9, U2.37 (P$37/PIO)
BIN13: J3.P$11, U2.41 (P$41/PIO/CBSEL0)
BIN14: J3.P$2, U2.27 (P$27/PIO)
BIN15: J3.P$4, U2.29 (P$29/PIO)
BIN16: J3.P$6, U2.33 (P$33/GBIN/PIO)
BIN17: J3.P$8, U2.36 (P$36/PIO)
BIN18: J3.P$10, U2.40 (P$40/PIO)
BIN19: J3.P$12, U2.42 (P$42/PIO/CBSEL1)
CDONE: IC1.35 (P35/RA9), R4.2, U2.43 (P$43/CFG/CDONE)
CRESET: IC1.34 (P34/RA4), R5.2, U2.44 (P$44/CFG/CRESET)
FBIN0: IC1.1 (P1/RB9), U2.19 (P$19/DPIO/8B)
FBIN1: IC1.2 (P2/RP22/RC6), U2.18 (P$18/DPIO/8A)
FBIN2: IC1.3 (P3/RP23/RC7), U2.16 (P$16/DPIO/7B)
FBIN3: IC1.4 (P4/RP24/RC8), U2.15 (P$15/GBIN6/7A)
GND: C1.2, C3.2, C4.2, C5.2, C6.1, C7.2, C8.2, C9.2, C10.2, C11.2, C12.2, C13.2, C14.2, C15.2, C16.2, C17.2, C18.2, C19.2, C20.2, C21.2, C22.2, C23.2, C24.2, C25.2, C26.2, IC1.16 (P16/AVSS), IC1.29 (P29/VSS), IC1.39 (P39/VSS), J2.P$2, J3.P$13, J4.P$6, J4.P$7, J7.P$3 (P$3/GND), R6.1, R7.1, U2.5 (P$5/GND), U2.17 (P$17/GND), U2.23 (P$23/GND), U2.32 (P$32/GND), U2.39 (P$39/GND), U2.47 (P$47/GND), U2.55 (P$55/GND), U2.70 (P$70/GND), U2.84 (P$84/GND), U2.98 (P$98/GND), U3.1, U4.1, U6.1
MISO: IC1.43 (P43/RP7/RB7), U2.45 (P$45/SPI/SDO)
MODE: IC1.33 (P33/RB4), R9.1
MOSI: IC1.38 (P38/RP21/RC5), U2.46 (P$46/SPI/SDI)
unnamed: IC1.42 (P42/VBUS), R3.1
unnamed: D2.C, U2.75 (P$75/VPP2V5)
unnamed: IC1.18 (P18/!MCLR), R1.2
unnamed: IC1.11 (P11/RB13), R8.2
unnamed: C6.2, IC1.7 (P7/VCAP)
unnamed: LED1.C, R7.2
unnamed: LED3.C, R9.2
PGC: IC1.20 (P20/RP6/RA1), J7.P$5 (P$5/PGC)
PGD: IC1.19 (P19/RP5/RA0), J7.P$4 (P$4/PGD)
REFO: R8.1, U2.13 (P$13/GBIN7/6B)
SCK: IC1.37 (P37/RP20/RC4), U2.48 (P$48/SPI/SCK)
USB-D+: IC1.8 (P8/D+), J2.P$6, U3.3
USB-D-: IC1.9 (P9/D-), J2.P$4, U3.2
VBUS: J2.P$8, R3.2
VCCINT: C15.1, C16.1, C19.1, C21.1, C22.1, C23.1, C24.1, C25.1, C26.1, U2.11 (P$11/VCC), U2.35 (P$35/VCC), U2.61 (P$61/VCC), U2.77 (P$77/VCC), U6.3
VDD: C1.1, C3.1, C7.1, C8.1, C9.1, C10.1, C11.1, C12.1, C13.1, C14.1, C18.1, C20.1, D2.A, IC1.10 (P10/VUSB), IC1.28 (P28/VDD), IC1.40 (P40/VDD), J4.P$4, J7.P$2 (P$2/VDD), L1.1, L2.1, LED1.A, LED3.A, R2.2, R4.1, R5.1, U2.6 (P$6/VCCIO), U2.14 (P$14/VCCIO), U2.22 (P$22/VCCIO), U2.31 (P$31/VCCIO), U2.38 (P$38/VCCIO), U2.50 (P$50/SPI/VCC), U2.58 (P$58/VCCIO), U2.67 (P$67/VCCIO), U2.88 (P$88/VCCIO), U2.92 (P$92/VCCIO), U4.3, U6.2, U6.2@1

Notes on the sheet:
3.3V
5.0V
GND
AREF
BIN0
BIN1
BIN2
BIN3
BIN4
BIN5
BIN6
BIN7
USB-D-
USB-D+
VBUS
BIN12
BIN13
BIN14
BIN15
BIN8
BIN9
BIN10
BIN11
SCL
SDA
BIN16
BIN17
BIN18
BIN19
BIN20
BIN21


Board: 2 copper layers, 71.1 x 55.9 mm, 49 parts (0 on the bottom side), 48 nets.

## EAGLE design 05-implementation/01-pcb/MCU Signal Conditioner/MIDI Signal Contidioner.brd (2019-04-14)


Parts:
C1, C2, C3: 100n; C0805
C5, C6: 1u; C0805
J2, J3: ARDUINO-CONN-8X2
R1, R2: 2.2K; R0805W
R3, R5, R7, R9: 10K; R0805W
R4, R6, R8, R10: 20K; R0805W
U4: 24CS01; 24CS01-SO8
U6: MCP1700-SOT89
U$2: 74LVC4245A; 74LVC4245A-SO24
X1, X2, X3, X4: SSW-107-02-G-D
X5, X7: MINI-USB-SHIELD-32005-201; MINI-USB-32005-201
X6: USB-787616; USB

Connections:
+3V3: C1.1, C3.1, C6.1, R1.1, R2.1, U4.8 (P$8/VCC), U6.3, U$2.23 (P$23/VCCB), U$2.24 (P$24/VCCB)
+5V: C2.1, C5.1, J3.P$13, U6.2, U6.2@1, U$2.1 (P$1/VCCA), X1.1, X1.14, X2.1, X2.14, X3.1, X3.14, X4.1, X4.14, X5.1
DI1: R3.1, X4.3, X4.4
DI1-3V: J3.P$12, R3.2, R4.1
DI2: R5.1, X4.5, X4.6
DI2-3V: J3.P$11, R5.2, R6.1
DI3: R7.1, X4.7, X4.8
DI3-3V: J3.P$10, R7.2, R8.1
DI4: R9.1, X4.9, X4.10
DI4-3V: J3.P$9, R9.2, R10.1
DO1: U$2.6 (P$6/A3), X2.3, X2.4
DO1-3V: J3.P$4, U$2.18 (P$18/B3)
DO2: U$2.5 (P$5/A2), X2.5, X2.6
DO2-3V: J3.P$3, U$2.19 (P$19/B2)
DO3: U$2.4 (P$4/A1), X2.7, X2.8
DO3-3V: J3.P$2, U$2.20 (P$20/B1)
DO4: U$2.3 (P$3/A0), X2.9, X2.10
DO4-3V: J3.P$1, U$2.21 (P$21/B0)
DT1: U$2.10 (P$10/A7), X3.3, X3.4
DT1-3V: J3.P$8, U$2.14 (P$14/B7)
DT2: U$2.9 (P$9/A6), X3.5, X3.6
DT2-3V: J3.P$7, U$2.15 (P$15/B6)
DT3: U$2.8 (P$8/A5), X3.7, X3.8
DT3-3V: J3.P$6, U$2.16 (P$16/B1/B5)
DT4: U$2.7 (P$7/A4), X3.9, X3.10
DT4-3V: J3.P$5, U$2.17 (P$17/B4)
GND: C1.2, C2.2, C3.2, C5.2, C6.2, J2.P$1, J3.P$14, R4.2, R6.2, R8.2, R10.2, U4.1 (P$1/A0), U4.2 (P$2/A1), U4.3 (P$3/A2), U4.4 (P$4/GND), U4.7 (P$7/WP), U6.1, U$2.2 (P$2/DIR), U$2.11 (P$11/GND), U$2.12 (P$12/GND), U$2.13 (P$13/GND), U$2.22 (P$22/!OE), X1.2, X1.13, X2.2, X2.13, X3.2, X3.13, X4.2, X4.13, X5.5, X5.M1 (S1), X5.M2 (S2), X5.M3 (S3), X5.M4 (S4), X6.4, X7.5, X7.M1 (S1), X7.M2 (S2), X7.M3 (S3), X7.M4 (S4)
SCL: J2.P$11, J2.P$12, R1.2, U4.6 (P$6/SCL), X1.11, X1.12
SDA: J2.P$13, J2.P$14, R2.2, U4.5 (P$5/SDA), X1.9, X1.10
USB-D+: J2.P$5, X6.3, X7.3
USB-D-: J2.P$3, X6.2, X7.2
VBUS: J2.P$7, X6.1, X7.1

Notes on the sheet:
BIN18
BIN19


Board: 2 copper layers, 94.1 x 37.0 mm, 27 parts (1 on the bottom side), 32 nets.

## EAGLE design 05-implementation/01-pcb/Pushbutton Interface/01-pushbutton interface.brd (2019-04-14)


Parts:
C1, C2: 1u; C0805
C3: 100n; C0805
LED1, LED2, LED3, LED4: 559-XXX-007; LED
R1, R2, R3, R4: 100; R0805
R5, R6, R7, R8, R9, R10, R11, R12: 100K; R0805
R13, R14: 2.2K; R0805
S1, S2, S3, S4: PB-SWITCH; SWITCH
U1: MCP23008; MCP23008-SO18
U2: MCP1700-SOT89
U3: 219-3LPSTR
X1, X2: SSW-107-02-G-D

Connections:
+3V3: C1.1, C3.1, R1.1, R2.1, R3.1, R4.1, R5.1, R6.1, R7.1, R8.1, R9.1, R10.1, R11.1, R12.1, R13.1, R14.1, U1.18 (P$18/VDD), U2.3
+5V: C2.1, U2.2, U2.2@1, X1.1, X1.14, X2.1, X2.14
GND: C1.2, C2.2, C3.2, S1.P$2, S2.P$2, S3.P$2, S4.P$2, U1.9 (P$9/VSS), U2.1, U3.1, U3.2, U3.3, X1.2, X1.13, X2.2, X2.13
unnamed: R8.2, S1.P$1, U1.13 (P$13/GP3)
unnamed: R9.2, S2.P$1, U1.12 (P$12/GP2)
unnamed: LED4.P$1 (A), R1.2
unnamed: LED3.P$1 (A), R2.2
unnamed: LED2.P$1 (A), R3.2
unnamed: LED1.P$1 (A), R4.2
unnamed: LED1.P$2 (C), U1.17 (P$17/GP7)
unnamed: LED2.P$2 (C), U1.16 (P$16/GP6)
unnamed: LED3.P$2 (C), U1.15 (P$15/GP5)
unnamed: LED4.P$2 (C), U1.14 (P$14/GP4)
unnamed: R7.2, U1.3 (P$3/A2), U3.6
unnamed: R6.2, U1.4 (P$4/A1), U3.5
unnamed: R5.2, U1.5 (P$5/A0), U3.4
unnamed: R10.2, S3.P$1, U1.11 (P$11/GP1)
unnamed: R11.2, S4.P$1, U1.10 (P$10/GP0)
unnamed: R12.2, U1.6 (P$6/!RESET)
SCL: R14.2, U1.1 (P$1/SCL), X1.11, X1.12, X2.11, X2.12
SDA: R13.2, U1.2 (P$2/SDA), X1.9, X1.10, X2.9, X2.10


Board: 2 copper layers, 66.0 x 53.3 mm, 30 parts (0 on the bottom side), 21 nets.

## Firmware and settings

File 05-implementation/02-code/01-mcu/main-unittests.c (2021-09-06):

/**********************************************************************
 * main.c
 * 
 * Description
 * This program implements a test interface to determine if the electrical
 * interface between the MCU and FPGA was established correctly.
 * 
 * I/O
 *   SPI.MISO: this FPGA output is tested after configuration
 *   SPI.MOSI: this FPGA input is tested during configuration
 *   SPI.SCK:  this FPGA input is tested during configuration
 *   SPI.SS:   this FPGA input is tested during configuration
 *   FBIN.0:   this FPGA output is tested after configuration
 *   FBIN.1:   this FPGA output is tested after configuration
 *   FBIN.2:   this FPGA output is tested after configuration
 *   FBIN.3:   this FPGA output is tested after configuration
 *   MODE:     this MCU output is tested after configuration
 * 
 * Revision History
 * Date       Version Notes
 * 2021-04-02 1.1     Initial test succeeded using MCU as a pass-through.
 * 
 * Notes
 *********************************************************************/

#include <stdio.h>
#include <stdint.h>
#include "app.h"
#include "hal.h"
#include "globals.h"

int main(void)
{
    uint8_t uFpgaResult;
    Event *ev;
    
    App_Init();
    
    uFpgaResult = Hal_InitFpga();
    App_SetFpgaMode(uFpgaResult);
    
    Hal_InitPeripherals();
    Hal_InitInterrupts();
    
    InitGlobals();
    
    Hal_LedModeOn();
    
    for(;;)
    {
        Hal_WatchdogReset();
        Hal_IdleTasks();
        App_IdleTasks();
    }
    
    return (int)0;
}

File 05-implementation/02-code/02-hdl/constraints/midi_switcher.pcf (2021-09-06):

# ##############################################################################

# iCEcube PCF

# Version:            2017.08.27940

# File Generated:     Feb 17 2018 06:34:16

# Family & Device:    iCE40HX1K

# Package:            VQ100

# ##############################################################################

###IOSet List 43
set_io clk 13
set_io gpio_fbin0 19
set_io gpio_fbin1 18
set_io gpio_fbin2 16
set_io gpio_fbin3 15
#set_io gpio_bin[0] 21
#set_io gpio_bin[1] 20
#set_io gpio_bin[2] 19
#set_io gpio_bin[3] 18
#set_io gpio_bin[0] 20
#set_io gpio_bin[1] 21
#set_io gpio_bin[2] 24
#set_io gpio_bin[3] 25
set_io midi_out[0] 26
set_io midi_out[2] 28
set_io midi_in[2] 30
set_io midi_in[0] 34
#set_io gpio_bin[8] 37
#set_io gpio_bin[9] 41
set_io midi_out[1] 27
set_io midi_out[3] 29
set_io midi_in[3] 33
set_io midi_in[1] 36
#set_io gpio_bin[14] 40
#set_io gpio_bin[15] 42
set_io spi_clk 48
set_io spi_miso 45
set_io spi_mosi 46
set_io spi_ss 49

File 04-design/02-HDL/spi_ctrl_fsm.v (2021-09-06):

module spi_ctrl_fsm(
    reset,
    clk,
    spi_rdy_i,
    timeout_i,
    cmd_i,
    wb_ack_i,
    spi_ld_o,
    ctl_spi_addr_o,
    ctl_spi_rd_o,
    ctl_wb_wr_o,
);

input  wire reset;
input  wire clk;
input  wire spi_rdy_i;
input  wire timeout_i;
input  wire cmd_i;
input  wire wb_ack_i;
//input  wire [7:0] spi_data_i;
output reg  spi_ld_o;
//output reg wb_we_o;
//output reg wb_stb_o;
output reg ctl_spi_addr_o;
output reg ctl_spi_rd_o;
output reg ctl_wb_wr_o;

parameter ST_IDLE    = 4'h0;
parameter ST_LAT_CMD = 4'h1;
parameter ST_CMD     = 4'h2;
parameter ST_WR_DATA = 4'h3;
parameter ST_WR_PREP = 4'h4;
parameter ST_WR_EXE  = 4'h5;
parameter ST_RD_PREP = 4'h6;
parameter ST_RD_EXE  = 4'h7;
parameter ST_RD_LOAD = 4'h8;
parameter ST_RD_DATA = 4'h9;
parameter ST_CLR     = 4'hA;

reg [3:0] int_curr_state;
reg [3:0] int_next_state;

always @(int_curr_state or cmd_i or spi_rdy_i or wb_ack_i)
begin: sm_cl
    case(int_curr_state)
    ST_IDLE: begin
        int_next_state = ST_IDLE;
        if (spi_rdy_i == 1'b1) begin
            int_next_state = ST_LAT_CMD;
        end
    end
    ST_LAT_CMD: begin
        int_next_state = ST_CMD;
    end
    ST_CMD: begin
        int_next_state = ST_RD_DATA;
        if (cmd_i == 1'b1) begin
            int_next_state = ST_WR_EXE;
        end
    end
    ST_WR_DATA: begin
        int_next_state = ST_WR_DATA;
        if (spi_rdy_i == 1'b1) begin
            int_next_state = ST_WR_PREP;
        end
    end
    ST_WR_PREP: begin
        int_next_state = ST_WR_EXE;
    end
    ST_WR_EXE: begin
        int_next_state =  ST_WR_EXE;
        if (wb_ack_i == 1'b1) begin
            int_next_state = ST_CLR;
        end
    end
    ST_RD_DATA: begin
        int_next_state = ST_CLR;
    end
/*
    ST_RD_PREP: begin
        int_next_state = ST_RD_EXE;
    end
    ST_RD_EXE: begin
        int_next_state = ST_RD_LOAD;
    end
    ST_RD_LOAD: begin
        int_next_state = ST_RD_DATA;
    end
 */
    ST_CLR: begin
        int_next_state = ST_IDLE;
    end
    default: begin
        int_next_state = ST_IDLE;
    end
    endcase
end
/*
always @(int_curr_state, spi_rdy_i, timeout_i, cmd_i, wb_ack_i)
begin: sm_cl
    case(int_curr_state)
    ST_IDLE: begin
        if (spi_rdy_i == 1) begin
            int_next_state = ST_LAT_CMD;
        end
        else begin
            int_next_state = ST_IDLE;
        end
    end
    ST_LAT_CMD: begin
        int_next_state = ST_CMD;
    end
    ST_CMD: begin
        if (timeout_i == 1) begin
            int_next_state = ST_IDLE;
        end
        else begin
            if (cmd_i == 1) begin
                int_next_state = ST_WR_DATA;
            end
            else begin
                int_next_state = ST_RD_PREP;
            end
        end
    end
    ST_WR_DATA: begin
        if (timeout_i == 1) begin
            int_next_state = ST_IDLE;
        end
        else begin
            if (spi_rdy_i == 1) begin
                int_next_state = ST_WR_PREP;
            end
            else begin
                int_next_state = ST_WR_DATA;
            end
        end
    end
    ST_WR_PREP: begin
        int_next_state = ST_WR_EXE;
    end
    ST_WR_EXE: begin
        if (timeout_i == 1) begin
            int_next_state = ST_IDLE;
        end
        else begin
            if (wb_ack_i == 1) begin
                int_next_state = ST_CLR;
            end
            else begin
                int_next_state = ST_WR_EXE;
            end
        end
    end
    ST_RD_PREP: begin
        int_next_state = ST_RD_EXE;
    end
    ST_RD_EXE: begin
        if (timeout_i == 1) begin
            int_next_state = ST_IDLE;
        end
        else begin
            if (wb_ack_i == 1) begin
                int_next_state = ST_RD_LOAD;
            end
            else begin
                int_next_state = ST_RD_EXE;
            end
        end
    end
    ST_RD_LOAD: begin
        int_next_state = ST_RD_DATA;
    end
    ST_RD_DATA: begin
        if (timeout_i == 1) begin
            int_next_state = ST_IDLE;
        end
        else begin
            if (spi_rdy_i == 1) begin
                int_next_state = ST_CLR;
            end
            else begin
                int_next_state = ST_RD_DATA;
            end
        end
    end
    ST_CLR: begin
        int_next_state = ST_IDLE;
    end
    default: begin
        int_next_state = ST_IDLE;
    end
    endcase
end
*/

always @(posedge clk)
begin: bhv_sm_sl
    if (reset == 1'b1) begin
        int_curr_state <= ST_IDLE;
    end
    else begin
        int_curr_state <= int_next_state;
    end
end
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

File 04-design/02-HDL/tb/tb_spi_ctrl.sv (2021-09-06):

/**********************************************************************
 * tb_spi_ctrl.sv
 *
 * This module implements the test bench for the spi_ctrl module.
 *
 * Status
 * in development
 *
 * Notes
 * write operations don't trigger a transition to the write states.
 * this is mostly working, but there are some issues.
 *********************************************************************/
//`timescale 1ns/1ps

`include "verilog_assert.vh"

module tb(
);

reg clk;
reg [2:0] sck_in;
reg spi_enable;
reg spi_mosi;
wire spi_miso;
reg rst;
wire spi_sck;
integer ii;
wire [7:0] wb_addr;
reg  [7:0] wb_dat_i;
wire [7:0] wb_dat_o;
wire wb_stb;
wire wb_ack;
wire wb_we;
reg spi_ss;
reg [7:0] spi_data_o;

always #4 clk <= ~clk;

assign wb_ack = wb_stb;

assign spi_sck = (spi_enable == 1) ? sck_in[2] : 1;

always @(posedge clk)
begin: bhv_sck
    sck_in <= sck_in + 1;
end

task spi_xchg;
    input [7:0] datai;
    output [7:0] datao;

    /* setup frame: initialize clock input for clock driver and assert ss */
    /* SR samples on the falling edge and outputs on rising edge */
    begin
    @(posedge sck_in[2]);

    spi_ss = 0;
    spi_enable = 1;
    spi_mosi = datai[7];
    @(negedge spi_sck);
    datao[7] = spi_miso;

    @(posedge spi_sck);
    spi_mosi = datai[6];
    @(negedge spi_sck);
    datao[6] = spi_miso;

    @(posedge spi_sck);
    spi_mosi = datai[5];
    @(negedge spi_sck);
    datao[5] = spi_miso;

    @(posedge spi_sck);
    spi_mosi = datai[4];
    @(negedge spi_sck);
    datao[4] = spi_miso;

    @(posedge spi_sck);
    spi_mosi = datai[3];
    @(negedge spi_sck);
    datao[3] = spi_miso;

    @(posedge spi_sck);
    spi_mosi = datai[2];
    @(negedge spi_sck);
    datao[2] = spi_miso;

    @(posedge spi_sck);
    spi_mosi = datai[1];
    @(negedge spi_sck);
    datao[1] = spi_miso;

    @(posedge spi_sck);
    spi_mosi = datai[0];
    @(negedge spi_sck);
    datao[0] = spi_miso;

    @(posedge spi_sck);

    spi_enable = 0;
    @(posedge sck_in[2]);
    spi_ss = 1;

    end
endtask

/* use sequential logic in the initial block to avoid race conditions */
initial begin
    $dumpfile("tb_spi_ctrl.vcd");
    $dumpvars(0, tb);

    rst = 0;
    clk = 0;
    spi_enable = 0;
    spi_mosi = 0;
    spi_ss = 1;
    sck_in = 0;
    
    /* initialize internal memory for sr0 instance */
    sc0.sr0.int_sr = 8'h00;
    sc0.sr0.int_sdo = 0;
    sc0.sr0.int_rdy = 0;
    
    sc0.int_spi_curr_state = 0;
    sc0.int_spi_next_state = 0;
    sc0.int_cmd = 0;
    sc0.int_addr = 0;
    sc0.int_data = 0;
    sc0.spi_ld = 0;
    sc0.int_wb_stb_o = 0;

    sc0.c0.int_cnt = 0;
    
    /* generate reset pulse */
    @(negedge clk);
    rst = 1;
    @(negedge clk);
    rst = 0;
    
    /* send the following sequence: write h80 to address 0 */
    #2048 @(posedge clk);
    spi_xchg(8'h80, spi_data_o);
    @(posedge sck_in[2]);
    spi_xchg(8'h01, spi_data_o);
    @(posedge sck_in[2]);

    /* send the following sequence: read address 0, provide clock for data */
    wb_dat_i = 8'h01;
    @(posedge clk);
    spi_xchg(8'h00, spi_data_o);
    @(posedge sck_in[2]);
    spi_xchg(8'h00, spi_data_o);
    @(posedge sck_in[2]);
    
    @(posedge clk);
    
    $finish;
end

spi_ctrl sc0(
    .reset(rst),
    .clk(clk),
    .spi_miso(spi_miso),
    .spi_mosi(spi_mosi),
    .spi_sck(spi_sck),
    .spi_ss(spi_ss),
    .wb_addr_o(wb_addr),
    .wb_dat_i(wb_dat_i),
    .wb_dat_o(wb_dat_o),
    .wb_stb_o(wb_stb),
    .wb_ack_i(wb_ack),
    .wb_we_o(wb_we)
);

endmodule

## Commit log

2018-04-06 Add prototype implementation source code.
    Add files to help in board bring-up testing.
    Add file for power-on reset on Lattice parts.
    Add FPGA files to assist in testing connectivity between MCU and FPGA.
    Add basic shift register implementation.
    Add constraint files for timing and pin placement.
    Add bare-bones MCU test code.
    [fpga.c, hal.c, hal.h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]
2018-04-07 Add requirements analysis.
    [Requirements Analysis.xlsx]
2018-04-07 Add files for PCB.
    [01-mcu.brd, 01-mcu.sch, 01-pushbutton interface.brd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]
2018-04-07 Update FPGA startup sequence for HX1K device.
2018-04-10 Add support for 1-msec timer. Add application logic for LED.
2018-04-10 Add system diagram to requirements analysis.
    [Requirements Analysis.xlsx]
2018-04-11 Change signal conditioner board to 3.3V rail.
    [MIDI Signal Contidioner.brd, MIDI Signal Contidioner.sch]
2018-04-11 Add schematic and pcb backup files to ignore list.
2018-04-12 Update signal conditioner.
    [MIDI Signal Contidioner.brd, MIDI Signal Contidioner.sch]
2018-04-12 Begin placement of components. Add Eagle exclusion to .gitignore.
    Begin placement of components on board to reduce board area.
    Add exclusion rules for Eagle to .gitignore.
    [MIDI Signal Contidioner.brd]
2018-04-12 Complete initial placement of components.
    [MIDI Signal Contidioner.brd, MIDI Signal Contidioner.sch]
2018-04-14 Update requirements analysis. Complete first pass at signal conditioner board. Add power analysis.
    [MIDI Signal Contidioner.brd, Power Analysis.xlsx, Requirements Analysis.xlsx]
2018-04-14 Add support for Timer1. Add guard conditions in FPGA configuration.
2018-04-16 Add comments to hal.c. Add application code to echo UART bytes.
2018-04-17 Add support for interrupts.
2018-04-17 Add SPI interrupt function to Hal.h. Update configuration bits.
2018-04-20 Update configuration bits. Add support for software-controlled watchdog timer.
2018-04-23 Add net analysis for critical nets in system.
    [Power Analysis.xlsx]
2018-04-24 Complete initial placement of signal conditioning board (5V).
    [MIDI Signal Contidioner.brd, MIDI Signal Contidioner.sch]
2018-04-24 Add connector analysis spreadsheet.
    [Connector Analysis.xlsx]
2018-04-25 Update signal conditioner board.
    [MIDI Signal Contidioner.brd]
2018-04-25 Update placement of signal conditioner footprints.
    [MIDI Signal Contidioner.brd]
2018-04-26 Complete layout of signal conditioner board.
    [MIDI Signal Contidioner.brd, MIDI Signal Contidioner.sch]
2018-05-03 Update footprint for regulator on signal conditioner board.
    [MIDI Signal Contidioner.brd, MIDI Signal Contidioner.sch]
2018-05-12 Add files to release PCB after successful board bring up.
    [01-mcu.brd, 01-mcu.sch, MCU bom.xlsx]
2018-05-13 Add problem reports for PCB bringup. Add code to correct reported problems on HW0001 R002.
    [Problem Report Status.xlsx]
2018-07-04 Update test logs from Logic Interface Board PCB bringup.
2018-09-02 Add files for PCB bringup.
    Update FPGA image with 3.3V I/O logic (counter bound to I/O pins).
    [Problem Report Status.xlsx]
2018-09-03 Revise MIDI PCB's for mechanical spacing of ribbon connector.
    [MIDI Input.brd, MIDI Output.brd, MIDI Output.sch]
2018-11-13 Add L2 requirements. Add FPGA concept drawing.
    [Requirements Analysis.xlsx]
2019-02-18 Add files for transition to KiCAD.
    [01-mcu.brd, 01-mcu.kicad_pcb, 01-mcu.sch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]
2019-04-07 Add files for PCB releases.
    [#37-1U.dwg, 01-mcu.brd, 37-1U.dwg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]
2019-04-12 Add files for initial placement of pushbutton interface.
    [01-pushbutton interface.brd, 01-pushbutton interface.sch]
2019-04-14 Add files for pushbutton PCB.
    [01-mcu.brd, 01-mcu.sch, 01-pushbutton interface.brd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]
2019-07-01 Archive Eagle design files and import to KiCAD.
    [MIDI Input.brd, MIDI Input.kicad_pcb, MIDI Input.sch]
2019-07-01 Finish moving eagle design.
    [MIDI Input.brd, MIDI Input.sch]
2019-07-02 Convert MIDI Output board to KiCAD.
    [MIDI Output.brd, MIDI Output.kicad_pcb, MIDI Output.sch]
2019-08-22 Add outline for mechanical front panel
    [front panel.dxf]
2019-10-09 Update requirements
    [Requirements Analysis.xlsx]
2019-10-10 Add experimental code to test section assignment. Add systemverilog testbench for SPI module.
2019-11-29 Add files to test board bringup.
2019-12-02 Add SPI interface file structure.
2019-12-21 Repair defect in SPI controller logic.
2019-12-23 Import pushbutton project to KiCAD.
    [01-pushbutton interface.kicad_pcb, 01-pushbutton interface.sch]
2019-12-23 Add unit tests for SPI controller. Update SPI interrupt setup.
2019-12-23 Update fpga-icestorm makefile. Add SPI logic to timer ISR.
2019-12-25 Repair defect in SPI interrupt configuration. Add support for updates in unit tests.
2019-12-26 Update PCB for pushbutton PCB to fill copper pours.
    [01-pushbutton interface.kicad_pcb]
2020-01-01 Add SPI controller implementation.
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2020-01-02 Add KiCAD import of MCU Signal Conditioner
    [MIDI Signal Contidioner.kicad_pcb, MIDI Signal Contidioner.sch]
2020-01-03 Verified board-to-board pinouts are consistent.
    [MIDI Signal Contidioner.kicad_pcb]
2020-01-06 Update MCU Signal Conditioner PCB for placement compatibility with MCU PCB.
    [MIDI Signal Contidioner.kicad_pcb]
2020-10-05 Update source files to fix unsynchronized inputs.
    [#37-1U.dwg, 01-mcu.brd, 01-mcu.kicad_pcb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]
2021-01-01 Add files to support simulation of SPI state machine.
2021-09-06 Add files for version 1.0.
    [20210602-FPGA RAM readout over SPI.xlsx, 20210604-FPGA RAM readout over SPI.xlsx, 20210702-FPGA RAM readout over SPI.xlsx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]
